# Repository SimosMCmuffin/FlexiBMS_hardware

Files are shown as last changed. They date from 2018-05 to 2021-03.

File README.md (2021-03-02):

# Note, this is not the hardware version of the "Lite"-version of the FlexiBMS, but an earlier tested and discontinued/abandoned concept of the BMS design. Lite HW is a new project that was started after this HW project was discontinued and is not currently in open-source circulation HW design wise.

# FlexiBMS_hardware
Open Source BMS developed by Simo Sihvonen (Simos MCmuffin) with the Esk8 community, for the Esk8 community.

This project was inspired by Raphael Chang's Battman project's hardware design (https://github.com/raphaelchang/battman-hardware)

More current news and happening related to this project can be found and followed over at the project thread at the electic-skateboard.builders forum: 
http://www.electric-skateboard.builders/t/flexibms-0-2-hw-under-work-flexible-configuration-and-charging-bms/46117

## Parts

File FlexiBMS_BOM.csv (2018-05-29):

Title | FlexiBMS
Revision | 0.2
Date | 2018-05-06
Generated | 29.5.2018 21:36:46
Company | SiMoS MCmuffin / Simo Sihvonen
Comment 1
Comment 2
Comment 3
Comment 4
Total Parts | 204
Total Unique Parts | 56
Ref | Value | Qty | Footprint | Datasheet | B25/85 | MFG | Power | TempCo. | Tol.
C1 C3 C5 C6 C7 C9 C11 C12 C27 C31 C37 C38 C39 C42 C44 C45 C46 C47 | 2µ2,16V | 18 | Capacitors_SMD:C_0603 |  |  | ANY |  | X5R
C2 C4 C63 C64 C65 | 10µ,63V | 5 | Capacitors_SMD:C_1210 |  |  | ANY |  | X7R
C8 C10 C13 C14 C15 C16 C17 C18 C19 C20 C21 C22 C23 C24 C25 C28 C30 C32 C33 C34 C43 | 100n,100V | 21 | Capacitors_SMD:C_0603 |  |  | ANY |  | X7R
C26 | 1µ,63V | 1 | Capacitors_SMD:C_1210 |  |  | ANY
C29 | 47µ,6V3 | 1 | Capacitors_SMD:C_1206 |  |  | ANY |  | X5R
C35 | 6n8,50V | 1 | Capacitors_SMD:C_0603 |  |  | ANY |  | X7R
C36 | 10µ,16V | 1 | Capacitors_SMD:C_1206 |  |  | ANY |  | X7R
C40 | 100µ,35V | 1 | Capacitors_SMD:CP_Elec_6.3x7.7 |  |  | EEE-FPV101XAP
C41 | 100µ,63V | 1 | Capacitors_SMD:CP_Elec_10x10 |  |  | EEE-FK1J101P
D1 | 12V | 1 | Diodes_SMD:D_SOD-323 |  |  | MM3Z12VT1G
D2 D3 D7 D9 D11 D13 D15 D17 D19 D21 D23 D25 D27 D29 D34 | LED | 15 | LEDs:LED_0603 |  |  | 150060RS75000
D4 D35 | CUS520 | 2 | Diodes_SMD:D_SOD-323 |  |  | CUS520 H3F
D5 | 62V | 1 | Diodes_SMD:D_SOD-123 |  |  | CMHZ5265B TR
D6 D8 D10 D12 D14 D16 D18 D20 D22 D24 D26 D28 | 7V5 | 12 | Diodes_SMD:D_SOD-323 |  |  | MM3Z7V5T1G
D30 | 53Vwm | 1 | Diodes_SMD:D_SMA |  |  | P4SMA62A-E3/61
D31 | 5,0Vwm | 1 | Diodes_SMD:D_SOD-123F |  |  | SMF5.0
D32 D33 | FSV1060V | 2 | TO_SOT_Packages_SMD:TO-277A |  |  | FSV1060V
J1 | Conn_02x08_Odd_Even | 1 | Pin_Headers:Pin_Header_Straight_2x08_Pitch2.54mm |  |  | PREC008DAAN-RC/"PPTC082LFBN-RC"/"SFH210-PPPC-D08-ID-BK"
J2 | USB_OTG | 1 | Connectors_USB:USB_Micro-B_Molex_47346-0001 |  |  | 10118192-0001LF OR "1051330011"
J3 | Conn_02x02 | 1 | Socket_Strips:Socket_Strip_Straight_2x02_Pitch2.54mm_SMD |  |  | M20-8750242
J4 J5 | JST_SMD_PH-04 | 2 | Connectors_JST:JST_PH_B4B-PH-SM4-TB_04x2.00mm_Straight |  |  | B4B-PH-SM4-TB(LF)(SN)
J6 | JST_XH-13 | 1 | Connectors_JST:JST_XH_S13B-XH-A_13x2.50mm_Angled |  |  | S13B-XH-A(LF)(SN)/"B13B-XH-A(LF)(SN)"
J7 J8 | GS3 | 2 | Connectors:GS3 |  |  | SolderBridge
L1 L2 L4 | BLM31PG330SN1L | 3 | Inductors_SMD:L_1206 |  |  | BLM31PG330SN1L
L3 | 22µ | 1 | Inductors_SMD:L_1210 |  |  | CBC3225T220MR
L5 | 22µ,6.3A | 1 | Custom_footprints:HC9 |  |  | HC9-220-R
LS1 | Speaker | 1 | Custom_footprints:CSS-0575 |  |  | CSS-0575A-SMT-TR
Q1 | DMP6023LE-13 | 1 | TO_SOT_Packages_SMD:SOT-223-3_TabPin2 |  |  | DMP6023LE-13
Q2 | DMN55D0UT-7 | 1 | smd-semi:SOT-523 |  |  | DMN55D0UT-7
Q3 Q4 | PMV50XPR | 2 | TO_SOT_Packages_SMD:SOT-23 |  |  | PMV50XPR
Q5 Q6 Q7 Q8 Q9 Q10 Q11 Q12 Q13 Q14 Q15 Q16 | BSS84PW | 12 | TO_SOT_Packages_SMD:SOT-323_SC-70 |  |  | BSS84PWH6327XTSA1
Q17 | BSZ100N06NSATMA1 | 1 | Custom_footprints:PG-TDSON-8 |  |  | BSZ100N06NSATMA1
R1 R72 R74 | 36k | 3 | Resistors_SMD:R_0603 |  |  | ANY |  |  | 1%
R2 R3 R71 | 510k | 3 | Resistors_SMD:R_0603 |  |  | ANY |  |  | 1%
R4 R6 R21 R23 R25 | 1M | 5 | Resistors_SMD:R_0603 |  |  | ANY |  |  | 1%
R5 R7 | 51k | 2 | Resistors_SMD:R_0603 |  |  | ANY |  |  | 1%
R8 R17 | 220k | 2 | Resistors_SMD:R_0603 |  |  | ANY |  |  | 1%
R9 R10 R15 R16 R18 R67 | 10k | 6 | Resistors_SMD:R_0603 |  |  | ANY |  |  | 1%
R11 R12 R19 R24 R68 | 4k7 | 5 | Resistors_SMD:R_0603 |  |  | ANY |  |  | 1%
R13 R14 R20 R22 R26 R73 R76 R77 | 120R | 8 | Resistors_SMD:R_0603 |  |  | ANY |  |  | 1%
R27 R28 R30 R31 R33 R34 R36 R37 R39 R40 R42 R43 R45 R46 R48 R49 R51 R52 R54 R55 R57 R58 R60 R61 R63 | 120R | 25 | Resistors_SMD:R_0402 |  |  | ANY |  |  | 1%
R29 R32 R35 R38 R41 R44 R47 R50 R53 R56 R59 R62 | 51R | 12 | Resistors_SMD:R_0805 |  |  | ANY | 0.5W |  | 5%
R64 R65 | 10R | 2 | Resistors_SMD:R_0603 |  |  | ANY |  |  | 1%
R66 | 10m | 1 | Resistors_SMD:R_1206 |  |  | ANY | 0.75W |  | 1%
R69 | 15m | 1 | Resistors_SMD:R_1206 |  |  | ANY | 0.75W |  | 1%
R70 | 18k | 1 | Resistors_SMD:R_0603 |  |  | ANY |  |  | 1%
SW1 SW2 | SW_Push | 2 | Buttons_Switches_SMD:SW_SPST_PTS810 |  |  | PTS810 SJK 250 SMTR LFS
TH2 | 10k | 1 | Resistors_SMD:R_0603 |  | 4300K | NCP18XH103J03RB |  |  | 5%
U1 U9 | AP2210N-3.3 | 2 | TO_SOT_Packages_SMD:SOT-23 |  |  | AP2210N-3.3TRG1
U2 | STM32L433CCT6 | 1 | Housings_QFP:LQFP-48_7x7mm_Pitch0.5mm |  |  | STM32L433CCT6
U3 | LTC6803-3 | 1 | Custom_footprints:FSOP-44_5.3x13.0mm_Pitch0.5mm |  |  | LTC6803IG-3#PBF
U4 | MAX17502F | 1 | Housings_DFN_QFN:DFN-10-1EP_2x3mm_Pitch0.5mm |  |  | MAX17502FATB+T
U5 | ISL28022 | 1 | Housings_SSOP:MSOP-10_3x3mm_Pitch0.5mm |  |  | ISL28022FUZ-T7A
U6 | LTC3873 | 1 | TO_SOT_Packages_SMD:TSOT-23-8 |  |  | LTC3873ETS8#TRMPBF
U7 | MAX5215 | 1 | Housings_SSOP:MSOP-8_3x3mm_Pitch0.65mm |  |  | MAX5215GUA+
U8 | TCAN330 | 1 | TO_SOT_Packages_SMD:SOT-23-8 |  |  | TCAN330DCNR
BOM made with KICAD_BOM_WIZARD (https://github.com/HashDefineElectronics/KiCad_BOM_Wizard.git)
Generated 29.5.2018 21:36:46

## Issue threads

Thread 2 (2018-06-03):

Some questions

Linjieqiang, 2018-06-03:
Hello Simos.

Happy to see your BMS project.

1. Why not use the TI BQ76940 not use LTC6803 as the Analog front chip to catch the each cell voltage and current and temperature?
2. Why not use the TI BQ76200 to controll the power switch?

SimosMCmuffin, 2018-06-04:
Good questions.

1. **Why not use TI's BQ769XX series ICs for the cell stack monitoring?** I had in fact in the beginning of the development looked at the before mentioned TI's chips, as a lower priced alternative to the LTC6803 series, but discovered the disappointing fact, that the overall cell support was less flexible with the TI's chips. I have pasted below a screenshot from the BQ769XX datasheet which shows the problem, there is no IC model that would support 4-12 amount of series cells and that is why I went with the LTC6803, because it gave the most flexibility for the series cells configuration.

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

2. **Why not use TI's BQ76200 for controlling the charge FET?** Remember that there is no discharge control on the main module, it would only be controlling a single high-side N-channel FET ideally, but that doesn't really make that much sense in the end. The charging currents we're talking about are low enough that a decently sized P-channel FET can be used with a simple low side N-channel FET to activate it. So IMO it's cheaper, less complex and uses less board space to go with the P-channel implementation.

Linjieqiang, 2018-06-04:
I am designing my BMS for my e-bike with TI BQ76940 12S.

Closed 2018-06-04.

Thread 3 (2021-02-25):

LiPo HV

13022591351, 2021-02-25:
Does the hardware support 4.35V high voltage LiPo?

SimosMCmuffin, 2021-03-01:
I will first ask a clarification question.

Are aware that this hardware repo is not the Lite-version of the FlexiBMS project, that is currently developed and sold, but an older, currently abandoned HW version of it?

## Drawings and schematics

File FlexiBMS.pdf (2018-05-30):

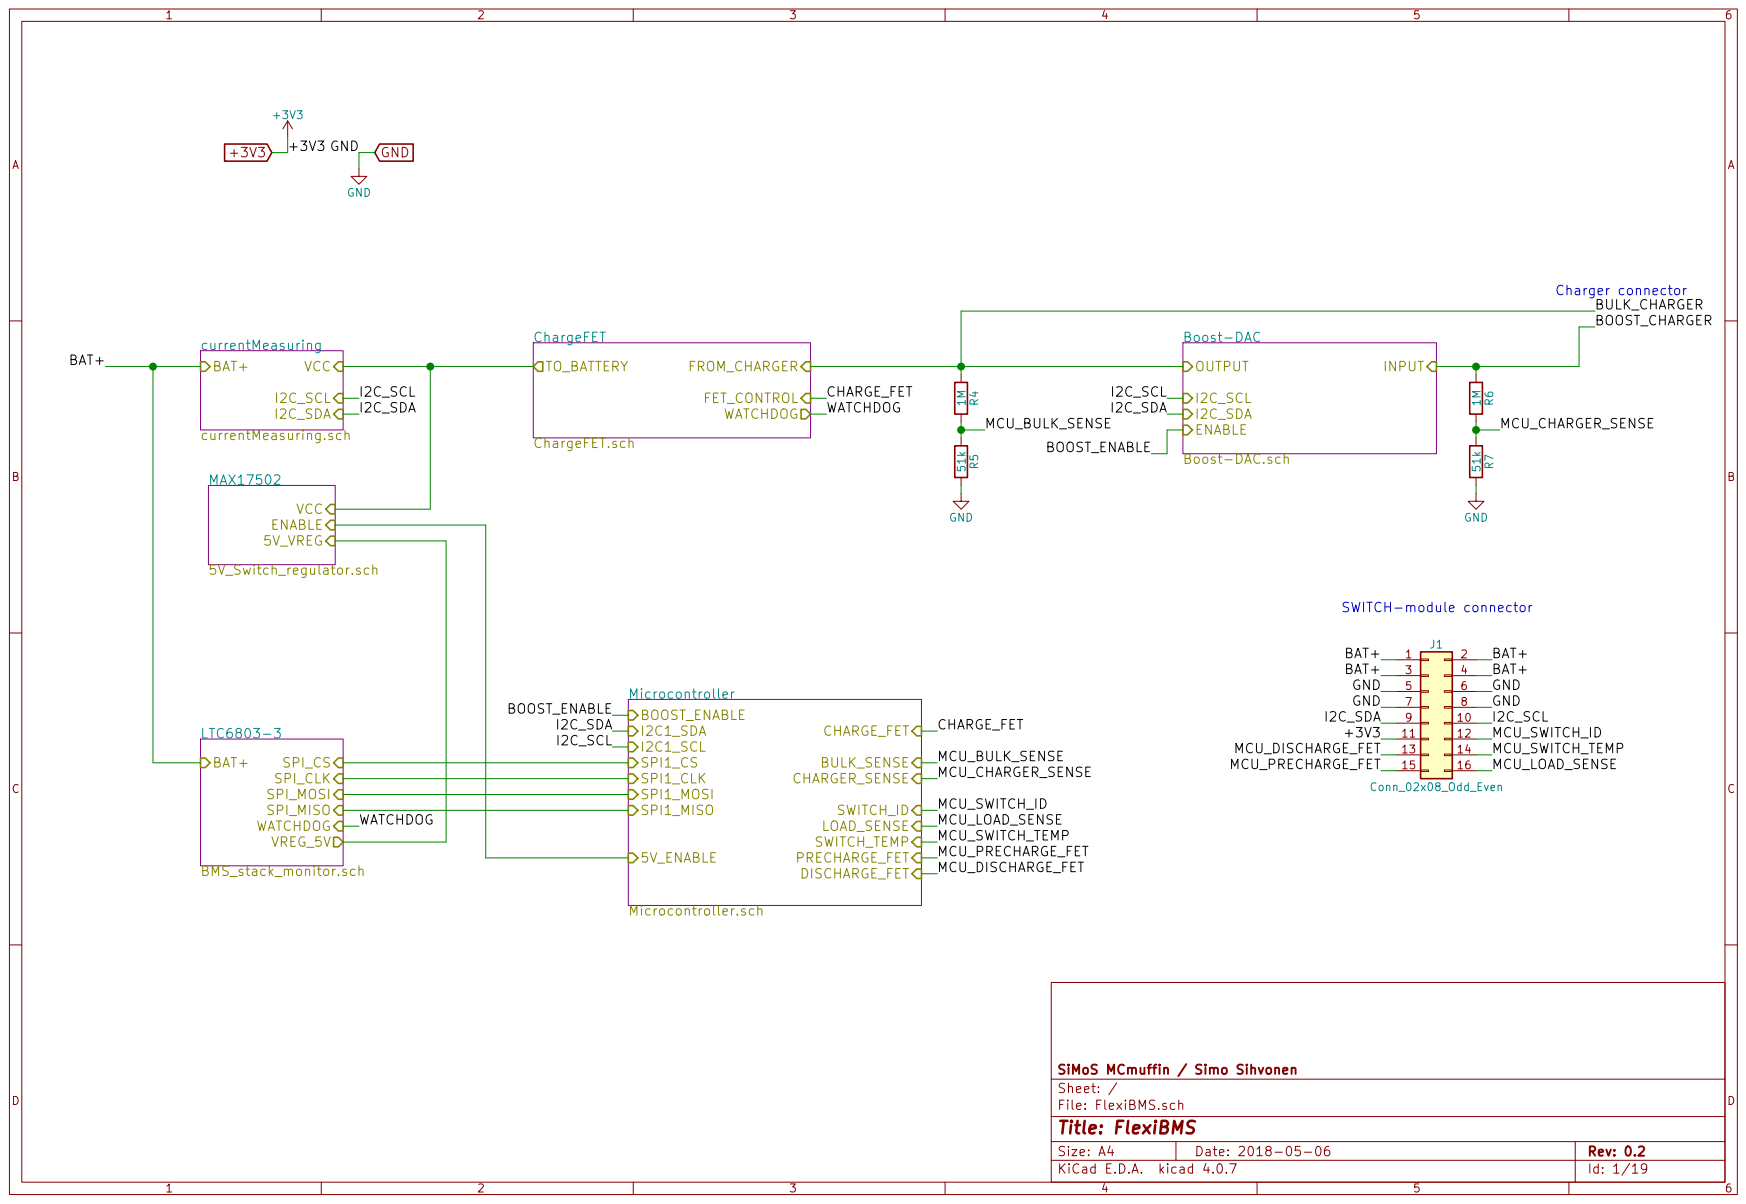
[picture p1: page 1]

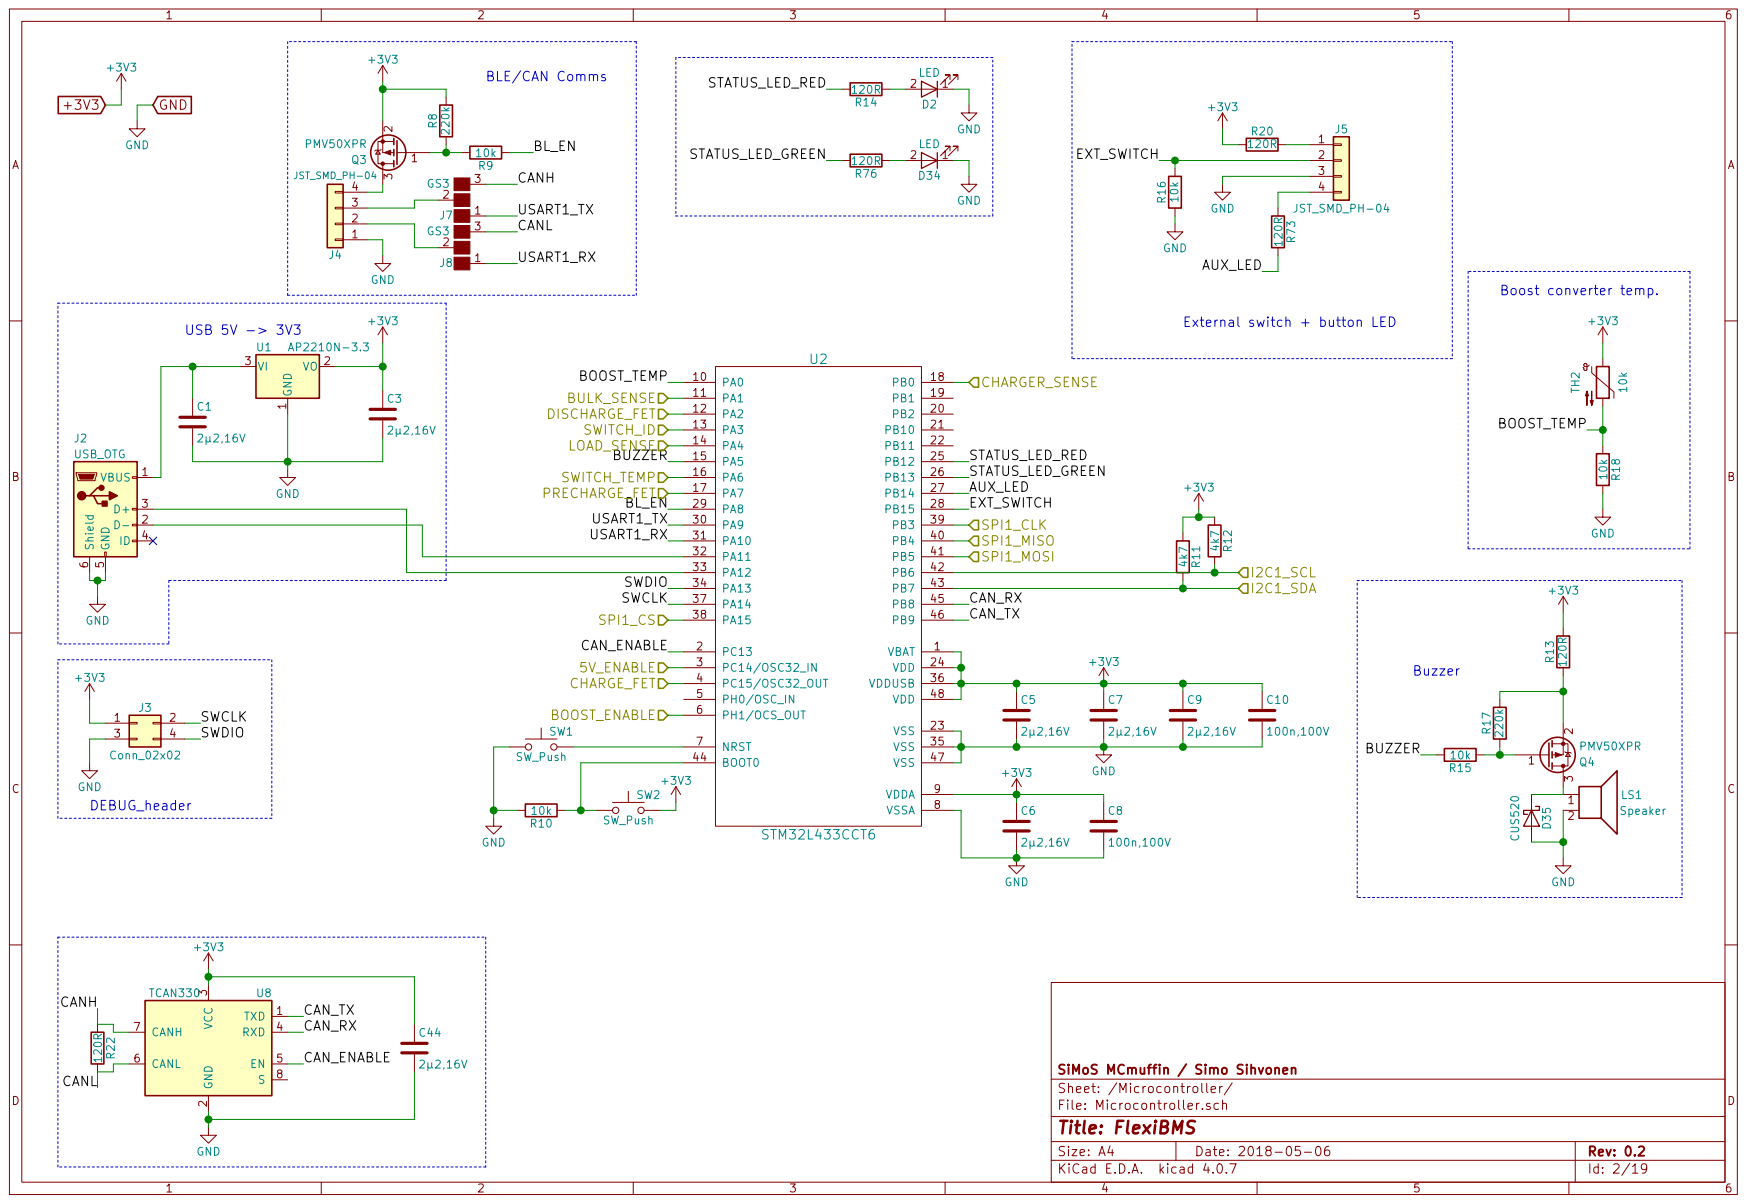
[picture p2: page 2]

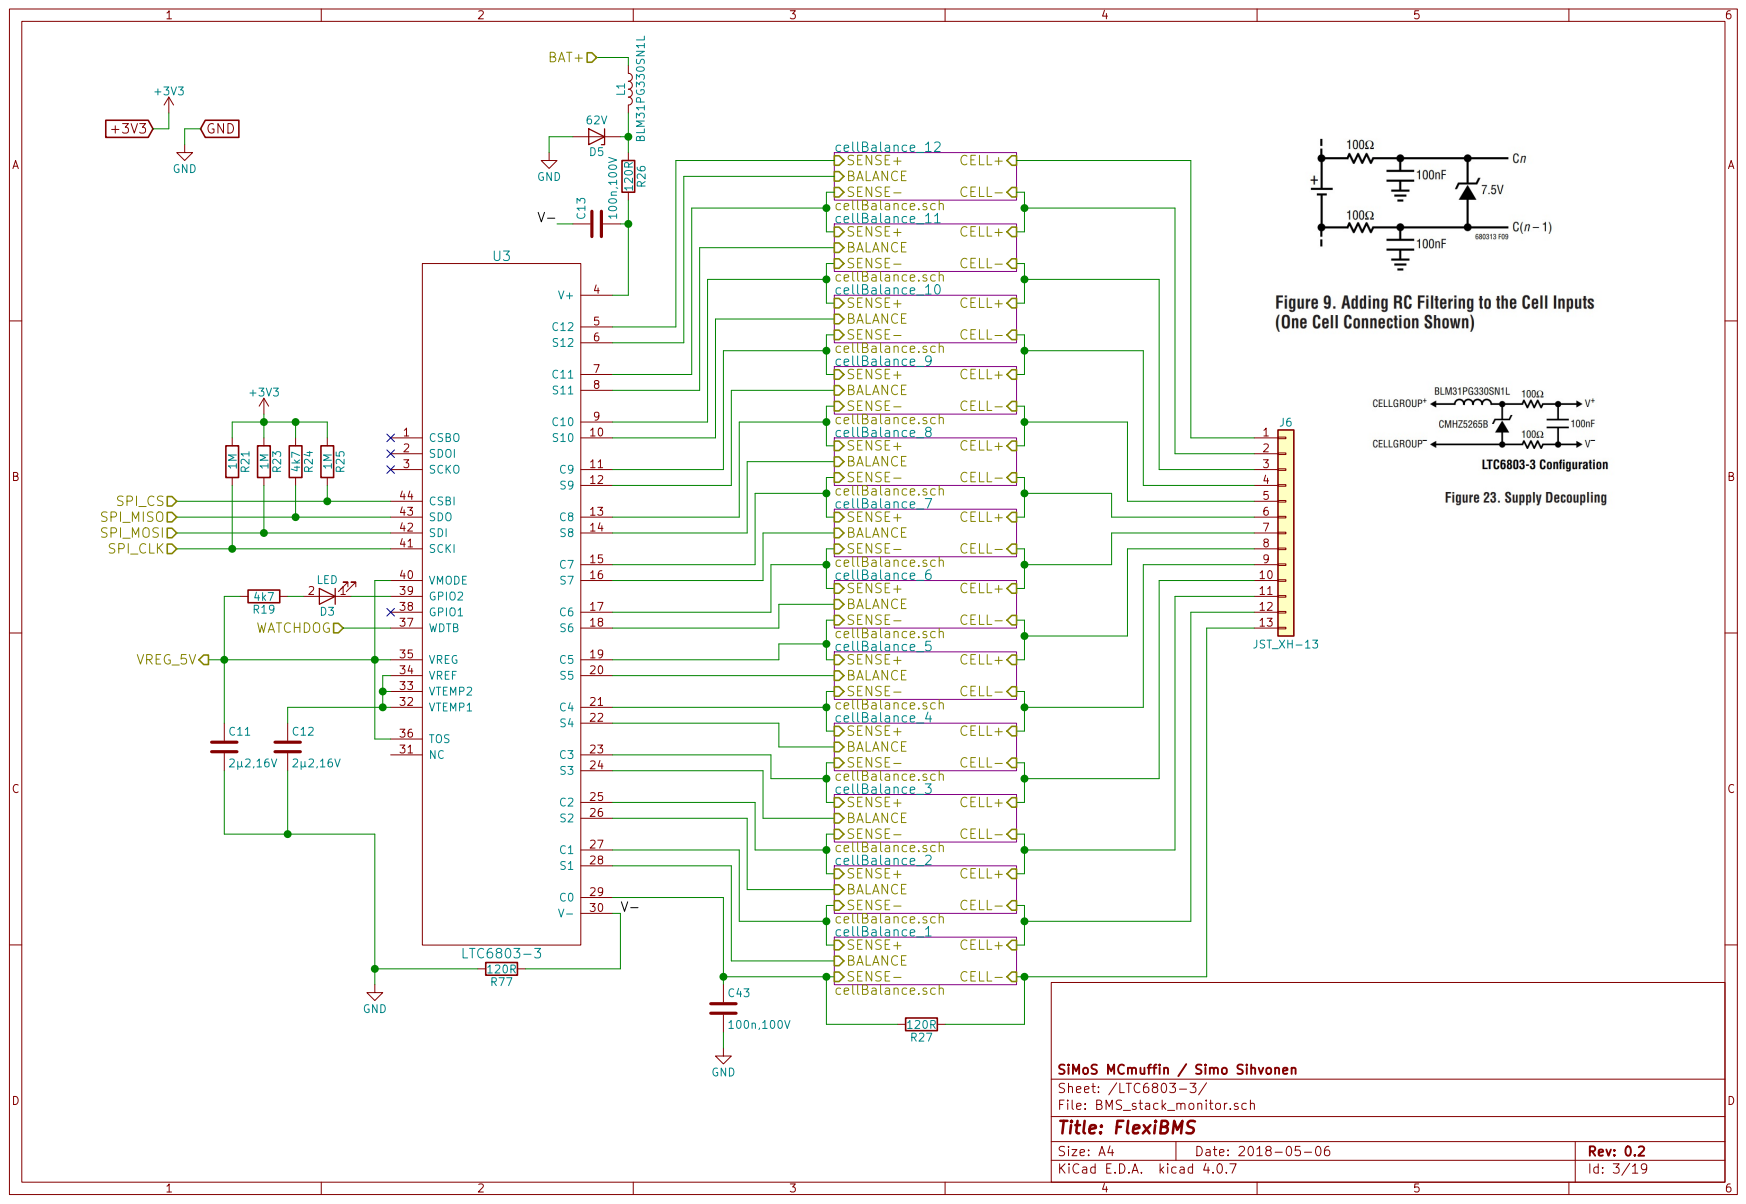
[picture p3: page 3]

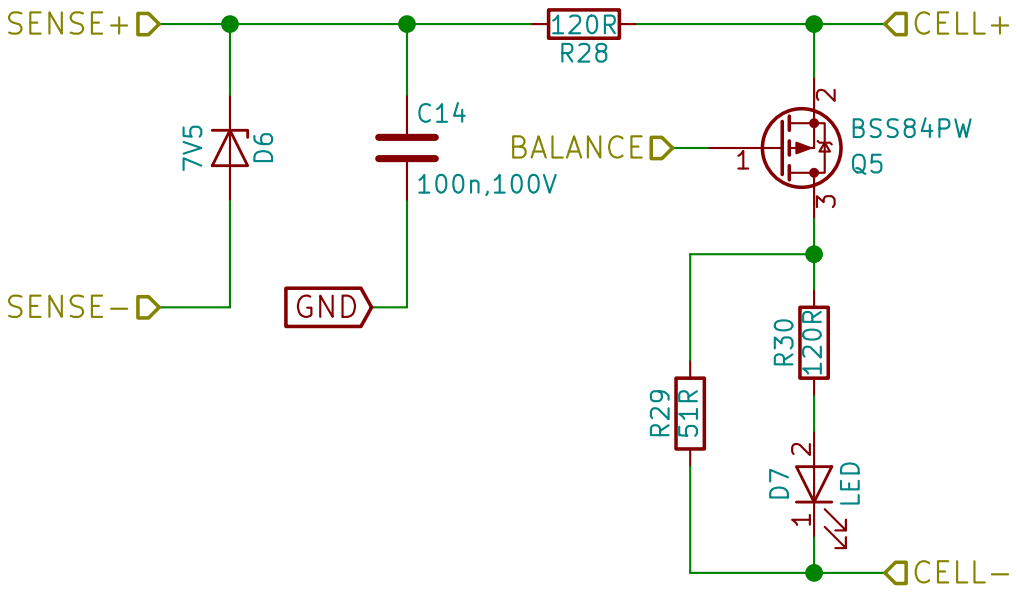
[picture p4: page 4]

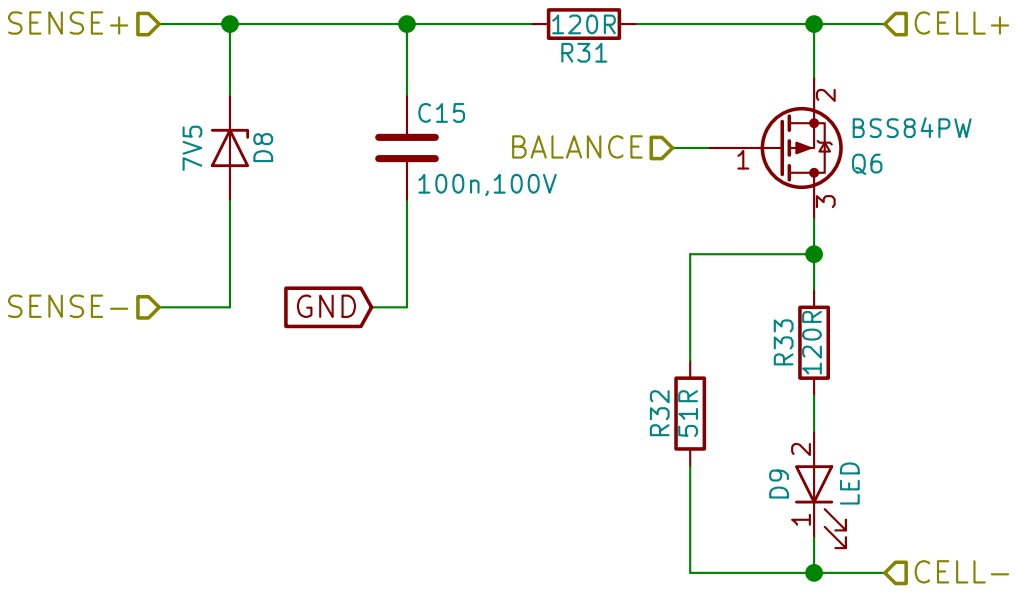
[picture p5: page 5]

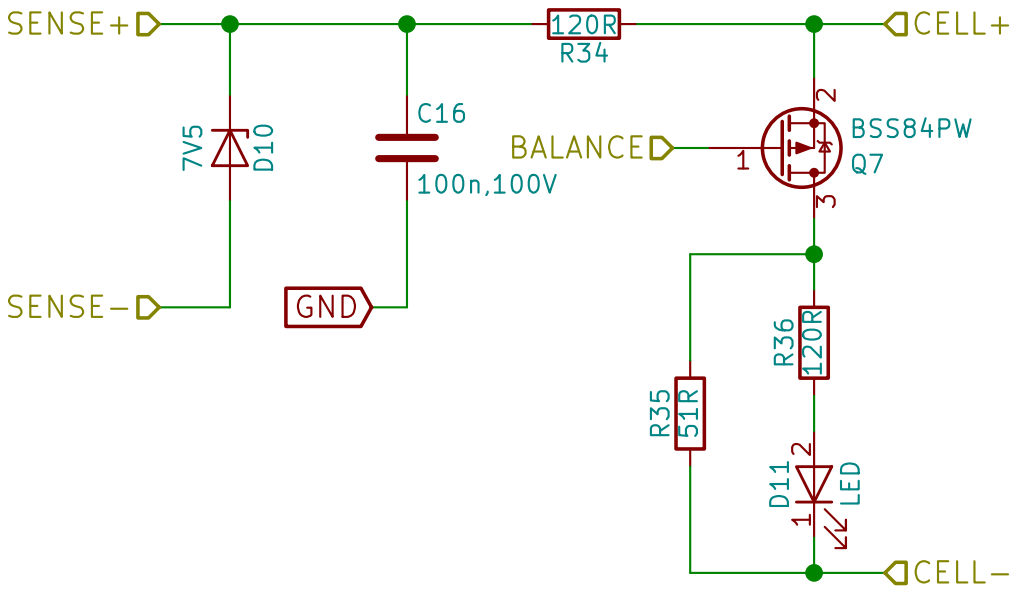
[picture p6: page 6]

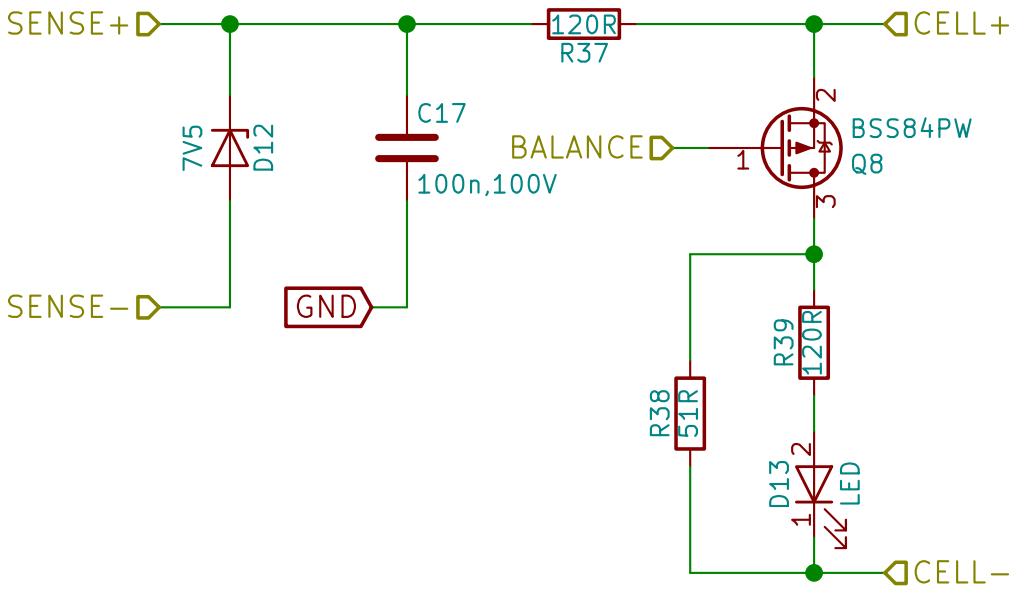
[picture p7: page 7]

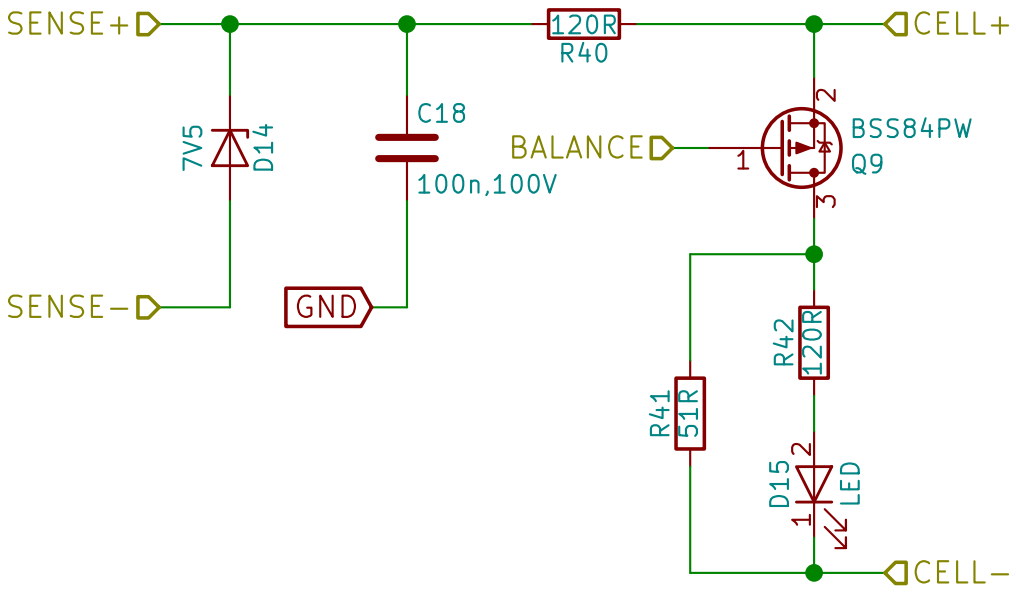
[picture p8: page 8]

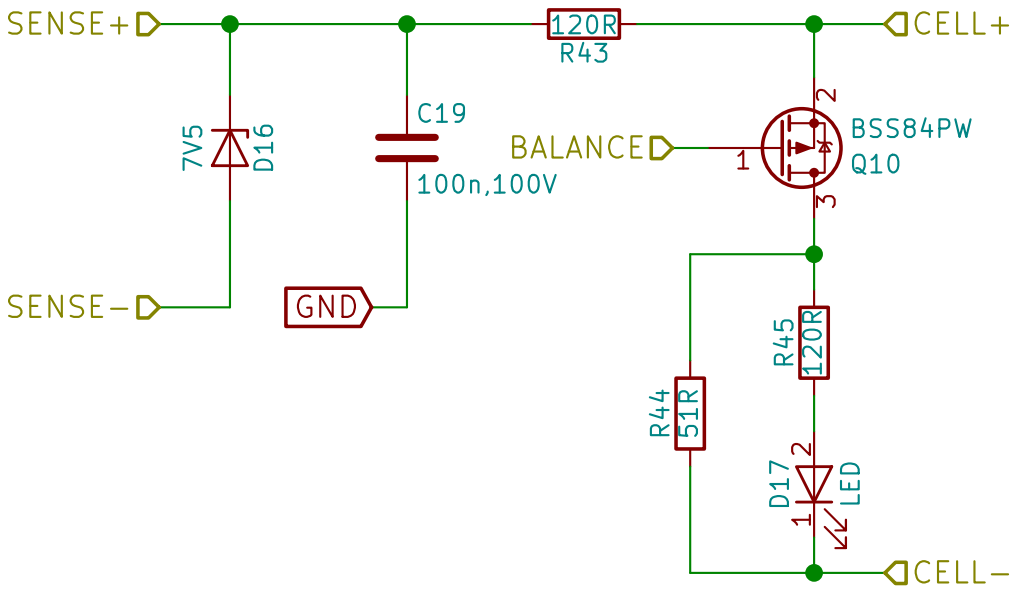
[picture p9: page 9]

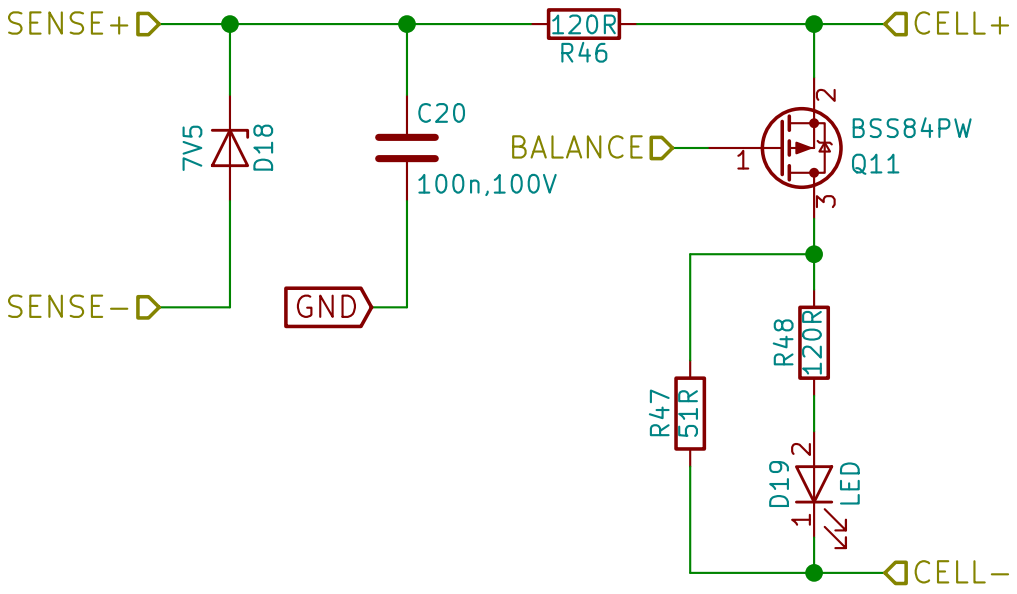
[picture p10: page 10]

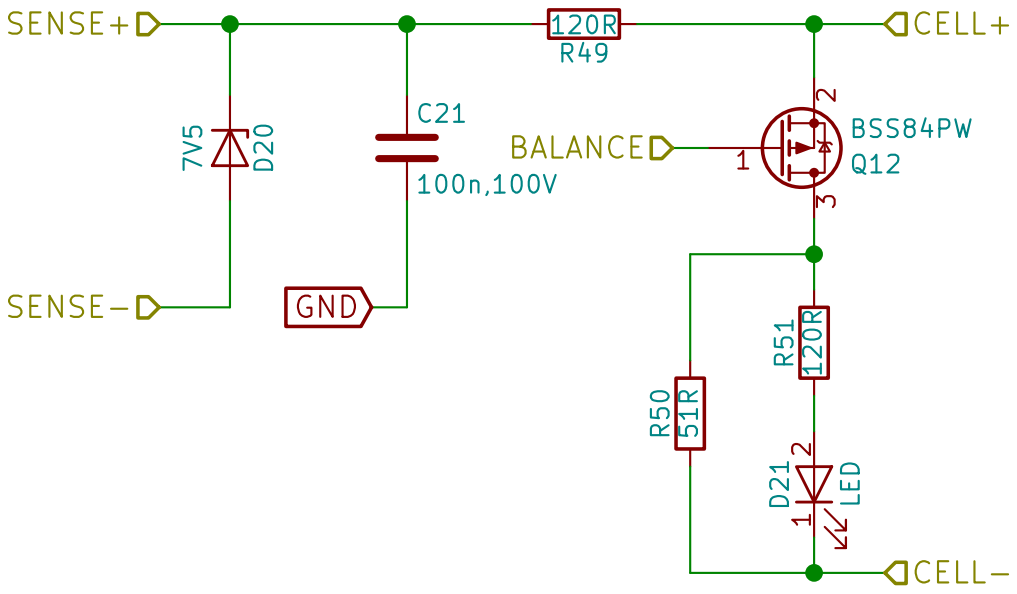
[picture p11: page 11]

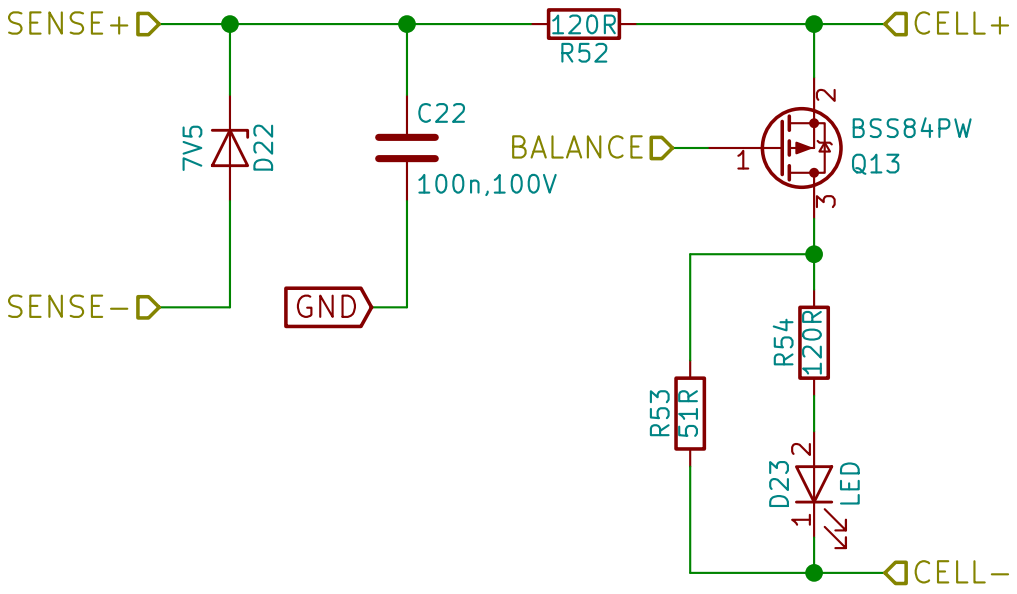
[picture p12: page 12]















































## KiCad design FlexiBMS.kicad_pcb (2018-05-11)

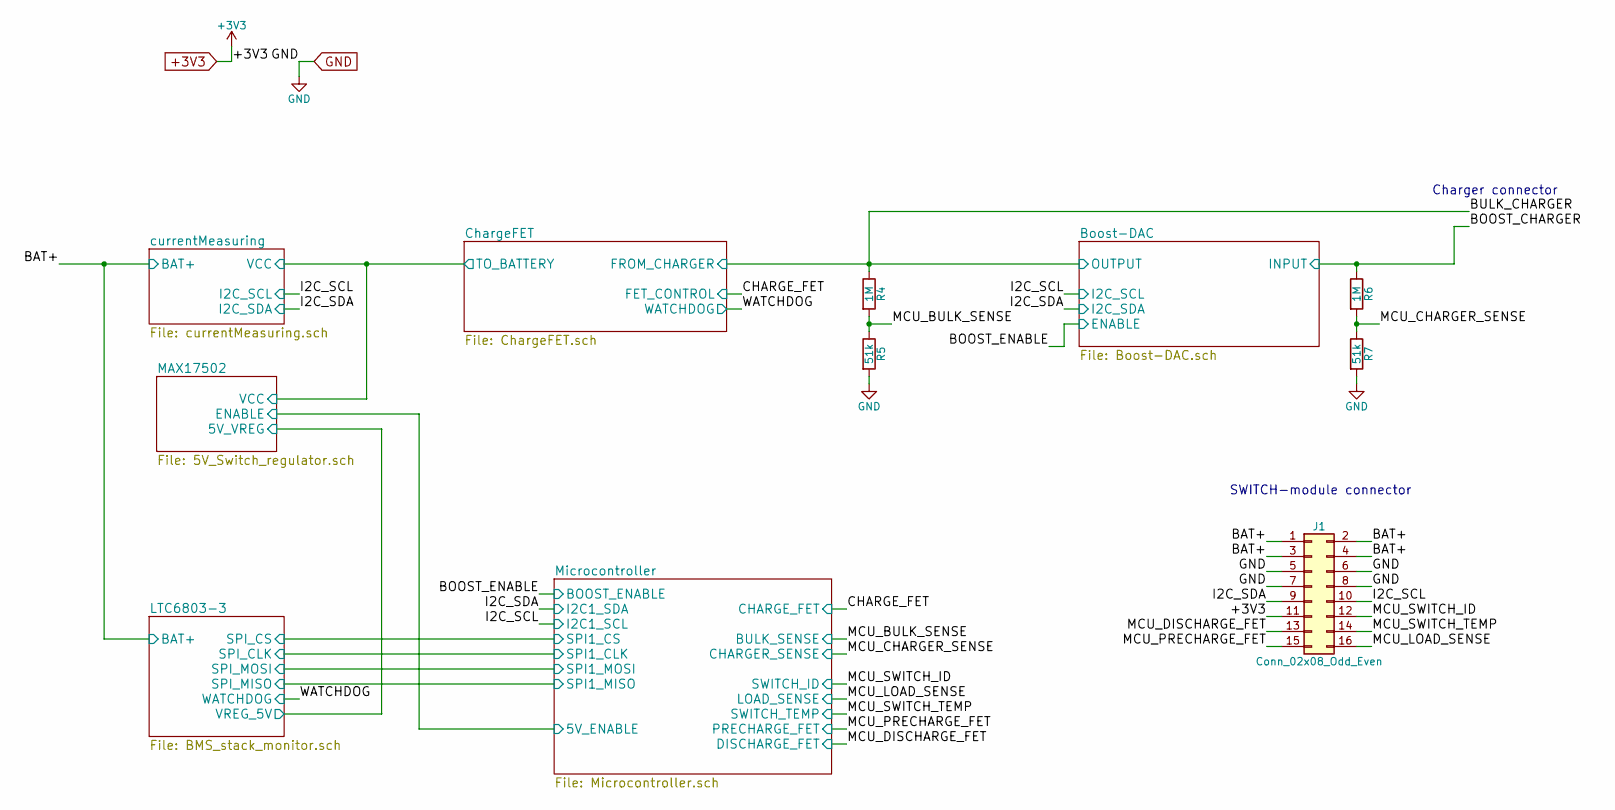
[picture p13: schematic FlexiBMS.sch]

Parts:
J1: Conn_02x08_Odd_Even; Pin_Header_Straight_2x08_Pitch2.54mm
R4, R6: 1M; R_0603
R5, R7: 51k; R_0603

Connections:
+3V3: J1.11; also elsewhere on the board
/BAT+: J1.1, J1.2, J1.3, J1.4; also elsewhere on the board
/BOOST_CHARGER: R6.1; also elsewhere on the board
/BULK_CHARGER: R4.1; also elsewhere on the board
/I2C_SCL: J1.10; also elsewhere on the board
/I2C_SDA: J1.9; also elsewhere on the board
/MCU_BULK_SENSE: R4.2, R5.1; also elsewhere on the board
/MCU_CHARGER_SENSE: R6.2, R7.1; also elsewhere on the board
/MCU_DISCHARGE_FET: J1.13; also elsewhere on the board
/MCU_LOAD_SENSE: J1.16; also elsewhere on the board
/MCU_PRECHARGE_FET: J1.15; also elsewhere on the board
/MCU_SWITCH_ID: J1.12; also elsewhere on the board
/MCU_SWITCH_TEMP: J1.14; also elsewhere on the board
GND: J1.5, J1.6, J1.7, J1.8, R5.2, R7.2; also elsewhere on the board

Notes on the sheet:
SWITCH-module connector
Charger connector

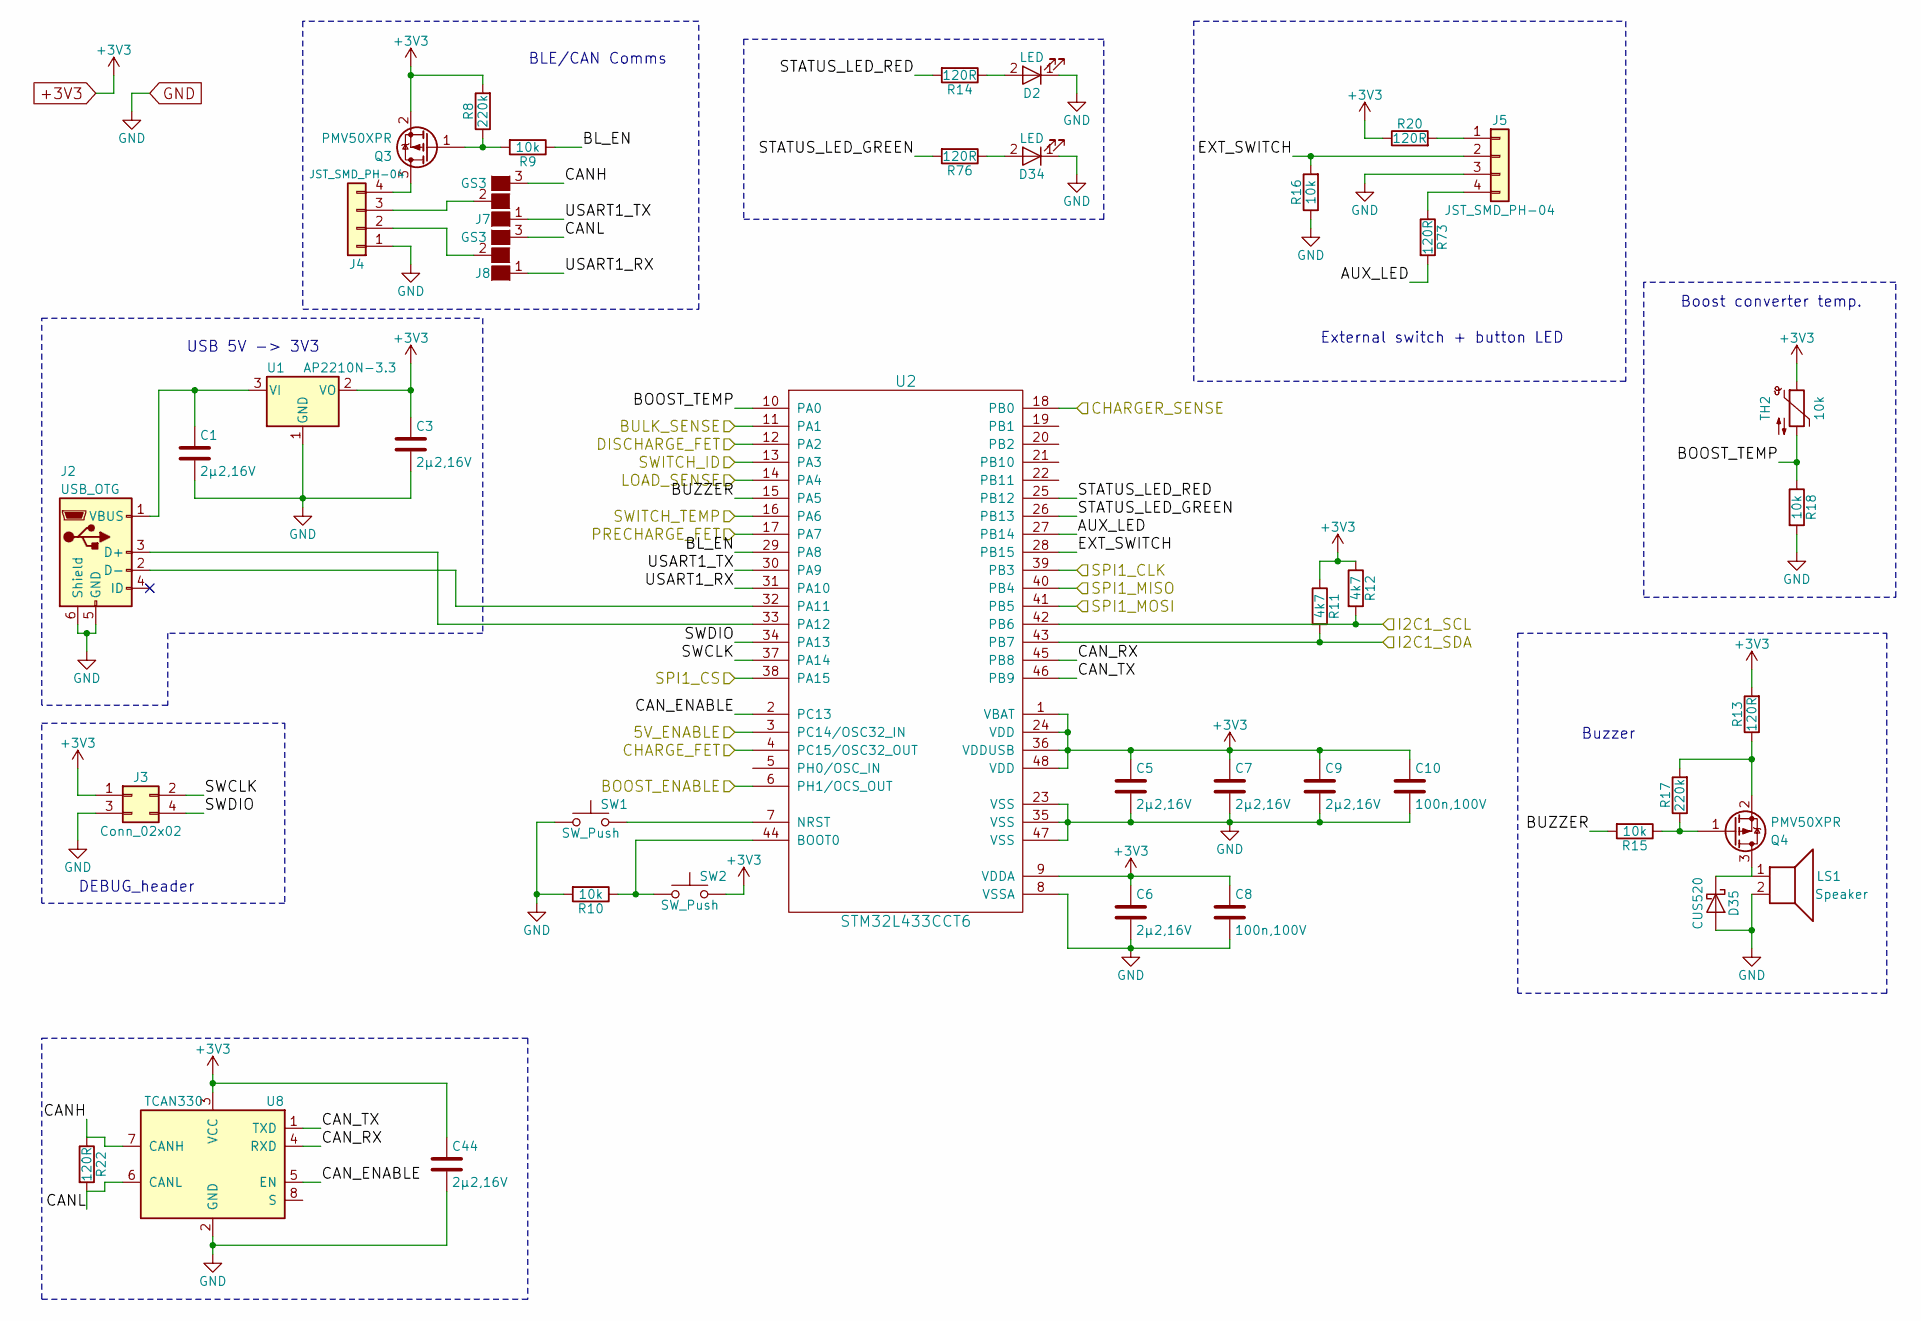
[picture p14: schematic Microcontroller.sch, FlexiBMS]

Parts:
C1, C3, C5, C6, C7, C9, C44: 2µ2,16V; C_0603
C8, C10: 100n,100V; C_0603
D2, D34: LED; LED_0603
D35: CUS520; D_SOD-323
J2: USB_OTG; USB_Micro-B_Molex_47346-0001
J3: Conn_02x02; Socket_Strip_Straight_2x02_Pitch2.54mm_SMD
J4, J5: JST_SMD_PH-04; JST_PH_B4B-PH-SM4-TB_04x2.00mm_Straight
J7, J8: GS3
LS1: Speaker; CSS-0575
Q3, Q4: PMV50XPR; SOT-23
R8, R17: 220k; R_0603
R9, R10, R15, R16, R18: 10k; R_0603
R11, R12: 4k7; R_0603
R13, R14, R20, R22, R73, R76: 120R; R_0603
SW1, SW2: SW_Push; SW_SPST_PTS810
TH2: 10k; R_0603
U1: AP2210N-3.3; SOT-23
U2: STM32L433CCT6; LQFP-48_7x7mm_Pitch0.5mm
U8: TCAN330; SOT-23-8

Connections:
+3V3: C3.1, C5.1, C6.1, C7.1, C8.1, C9.1, C10.1, C44.1, J3.1, Q3.2 (S), R8.2, R11.1, R12.1, R13.2, R20.1, SW2.2, TH2.1, U1.2 (VO), U2.1 (VBAT), U2.9 (VDDA), U2.24 (VDD), U2.36 (VDDUSB), U2.48 (VDD), U8.3 (VCC); also elsewhere on the board
/BOOST_ENABLE: U2.6 (PH1/OCS_OUT); also elsewhere on the board
/CHARGE_FET: U2.4 (PC15/OSC32_OUT); also elsewhere on the board
/I2C_SCL: R12.2, U2.42 (PB6); also elsewhere on the board
/I2C_SDA: R11.2, U2.43 (PB7); also elsewhere on the board
/MCU_BULK_SENSE: U2.11 (PA1); also elsewhere on the board
/MCU_CHARGER_SENSE: U2.18 (PB0); also elsewhere on the board
/MCU_DISCHARGE_FET: U2.12 (PA2); also elsewhere on the board
/MCU_LOAD_SENSE: U2.14 (PA4); also elsewhere on the board
/MCU_PRECHARGE_FET: U2.17 (PA7); also elsewhere on the board
/MCU_SWITCH_ID: U2.13 (PA3); also elsewhere on the board
/MCU_SWITCH_TEMP: U2.16 (PA6); also elsewhere on the board
/Microcontroller/5V_ENABLE: U2.3 (PC14/OSC32_IN); also elsewhere on the board
/Microcontroller/AUX_LED: R73.2, U2.27 (PB14)
/Microcontroller/BL_EN: R9.1, U2.29 (PA8)
/Microcontroller/BOOST_TEMP: R18.1, TH2.2, U2.10 (PA0)
/Microcontroller/BUZZER: R15.2, U2.15 (PA5)
/Microcontroller/CANH: J7.3 (G3), R22.1, U8.7 (CANH)
/Microcontroller/CANL: J8.3 (G3), R22.2, U8.6 (CANL)
/Microcontroller/CAN_ENABLE: U2.2 (PC13), U8.5 (EN)
/Microcontroller/CAN_RX: U2.45 (PB8), U8.4 (RXD)
/Microcontroller/CAN_TX: U2.46 (PB9), U8.1 (TXD)
/Microcontroller/EXT_SWITCH: J5.2, R16.2, U2.28 (PB15)
/Microcontroller/SPI1_CLK: U2.39 (PB3); also elsewhere on the board
/Microcontroller/SPI1_CS: U2.38 (PA15); also elsewhere on the board
/Microcontroller/SPI1_MISO: U2.40 (PB4); also elsewhere on the board
/Microcontroller/SPI1_MOSI: U2.41 (PB5); also elsewhere on the board
/Microcontroller/STATUS_LED_GREEN: R76.2, U2.26 (PB13)
/Microcontroller/STATUS_LED_RED: R14.2, U2.25 (PB12)
/Microcontroller/SWCLK: J3.2, U2.37 (PA14)
/Microcontroller/SWDIO: J3.4, U2.34 (PA13)
/Microcontroller/USART1_RX: J8.1 (G1), U2.31 (PA10)
/Microcontroller/USART1_TX: J7.1 (G1), U2.30 (PA9)
GND: C1.2, C3.2, C5.2, C6.2, C7.2, C8.2, C9.2, C10.2, C44.2, D2.1 (K), D34.1 (K), D35.2 (A), J2.5 (GND), J2.6 (Shield), J3.3, J4.1, J5.3, LS1.2, R10.2, R16.1, R18.2, SW1.1, U1.1 (GND), U2.8 (VSSA), U2.23 (VSS), U2.35 (VSS), U2.47 (VSS), U8.2 (GND); also elsewhere on the board
unnamed: C1.1, J2.1 (VBUS), U1.3 (VI)
unnamed: D2.2 (A), R14.1
unnamed: D34.2 (A), R76.1
unnamed: D35.1 (K), LS1.1, Q4.3 (D)
unnamed: J2.2 (D-), U2.32 (PA11)
unnamed: J2.3 (D+), U2.33 (PA12)
unnamed: J4.2, J8.2 (G2)
unnamed: J4.3, J7.2 (G2)
unnamed: J4.4, Q3.3 (D)
unnamed: J5.1, R20.2
unnamed: J5.4, R73.1
unnamed: Q3.1 (G), R8.1, R9.2
unnamed: Q4.1 (G), R15.1, R17.1
unnamed: Q4.2 (S), R13.1, R17.2
unnamed: R10.1, SW2.1, U2.44 (BOOT0)
unnamed: SW1.2, U2.7 (NRST)

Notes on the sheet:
Boost converter temp.
External switch + button LED
BLE/CAN Comms
Buzzer
USB 5V -> 3V3
DEBUG_header

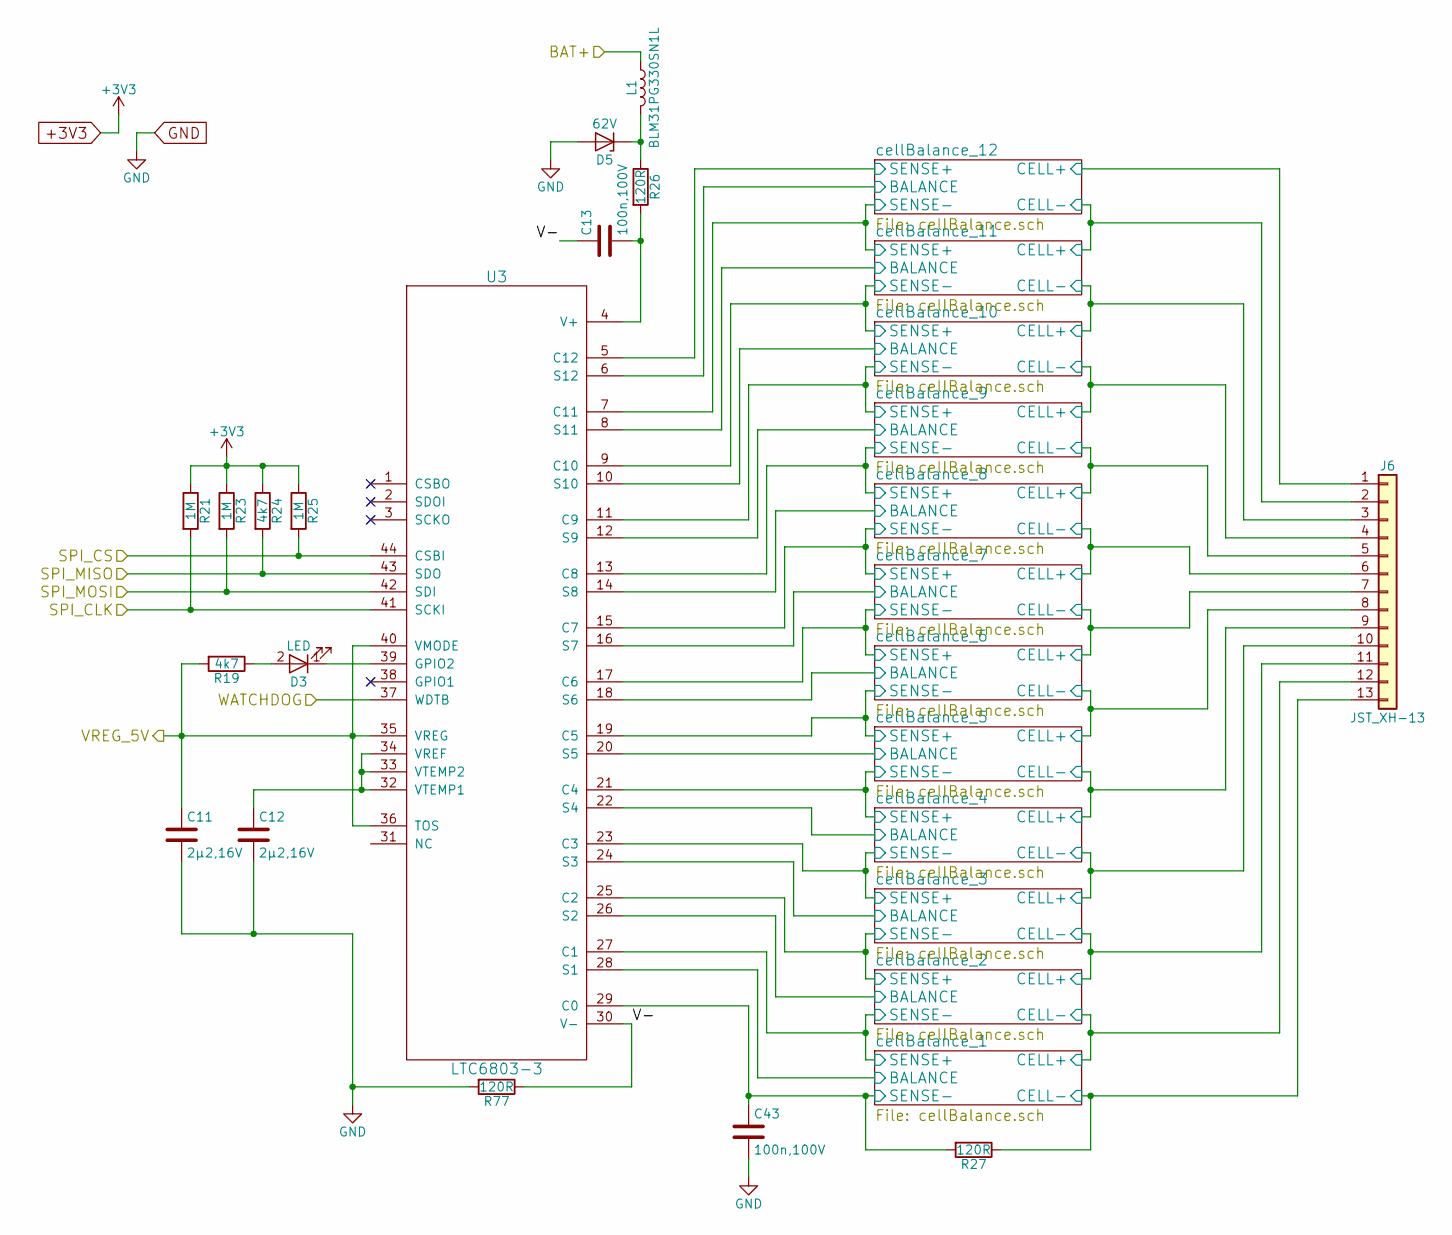
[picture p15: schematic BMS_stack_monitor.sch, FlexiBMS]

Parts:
C11, C12: 2µ2,16V; C_0603
C13, C43: 100n,100V; C_0603
D3: LED; LED_0603
D5: 62V; D_SOD-123
J6: JST_XH-13; JST_XH_S13B-XH-A_13x2.50mm_Angled
L1: BLM31PG330SN1L; L_1206
R19, R24: 4k7; R_0603
R21, R23, R25: 1M; R_0603
R26, R77: 120R; R_0603
R27: 120R; R_0402
U3: LTC6803-3; FSOP-44_5.3x13.0mm_Pitch0.5mm

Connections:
+3V3: R21.1, R23.1, R24.1, R25.1; also elsewhere on the board
/BAT+: L1.1; also elsewhere on the board
/LTC6803-3/V-: C13.1, R77.1, U3.30 (V-)
/LTC6803-3/cellBalance_1/BALANCE: U3.28 (S1); also elsewhere on the board
/LTC6803-3/cellBalance_1/CELL+: J6.12; also elsewhere on the board
/LTC6803-3/cellBalance_1/CELL-: J6.13, R27.1; also elsewhere on the board
/LTC6803-3/cellBalance_1/SENSE+: U3.27 (C1); also elsewhere on the board
/LTC6803-3/cellBalance_1/SENSE-: C43.1, R27.2, U3.29 (C0); also elsewhere on the board
/LTC6803-3/cellBalance_2/BALANCE: U3.26 (S2); also elsewhere on the board
/LTC6803-3/cellBalance_2/CELL+: J6.11; also elsewhere on the board
/LTC6803-3/cellBalance_2/SENSE+: U3.25 (C2); also elsewhere on the board
/LTC6803-3/cellBalance_3/BALANCE: U3.24 (S3); also elsewhere on the board
/LTC6803-3/cellBalance_3/CELL+: J6.10; also elsewhere on the board
/LTC6803-3/cellBalance_3/SENSE+: U3.23 (C3); also elsewhere on the board
/LTC6803-3/cellBalance_4/BALANCE: U3.22 (S4); also elsewhere on the board
/LTC6803-3/cellBalance_4/CELL+: J6.9; also elsewhere on the board
/LTC6803-3/cellBalance_4/SENSE+: U3.21 (C4); also elsewhere on the board
/LTC6803-3/cellBalance_5/BALANCE: U3.20 (S5); also elsewhere on the board
/LTC6803-3/cellBalance_5/CELL+: J6.8; also elsewhere on the board
/LTC6803-3/cellBalance_5/SENSE+: U3.19 (C5); also elsewhere on the board
/LTC6803-3/cellBalance_6/BALANCE: U3.18 (S6); also elsewhere on the board
/LTC6803-3/cellBalance_6/CELL+: J6.7; also elsewhere on the board
/LTC6803-3/cellBalance_6/SENSE+: U3.17 (C6); also elsewhere on the board
/LTC6803-3/cellBalance_7/BALANCE: U3.16 (S7); also elsewhere on the board
/LTC6803-3/cellBalance_7/CELL+: J6.6; also elsewhere on the board
/LTC6803-3/cellBalance_7/SENSE+: U3.15 (C7); also elsewhere on the board
/LTC6803-3/cellBalance_8/BALANCE: U3.14 (S8); also elsewhere on the board
/LTC6803-3/cellBalance_8/CELL+: J6.5; also elsewhere on the board
/LTC6803-3/cellBalance_8/SENSE+: U3.13 (C8); also elsewhere on the board
/LTC6803-3/cellBalance_9/BALANCE: U3.12 (S9); also elsewhere on the board
/LTC6803-3/cellBalance_9/CELL+: J6.4; also elsewhere on the board
/LTC6803-3/cellBalance_9/SENSE+: U3.11 (C9); also elsewhere on the board
/LTC6803-3/cellBalance_10/BALANCE: U3.10 (S10); also elsewhere on the board
/LTC6803-3/cellBalance_10/CELL+: J6.3; also elsewhere on the board
/LTC6803-3/cellBalance_10/SENSE+: U3.9 (C10); also elsewhere on the board
/LTC6803-3/cellBalance_11/BALANCE: U3.8 (S11); also elsewhere on the board
/LTC6803-3/cellBalance_11/CELL+: J6.2; also elsewhere on the board
/LTC6803-3/cellBalance_11/SENSE+: U3.7 (C11); also elsewhere on the board
/LTC6803-3/cellBalance_12/BALANCE: U3.6 (S12); also elsewhere on the board
/LTC6803-3/cellBalance_12/CELL+: J6.1; also elsewhere on the board
/LTC6803-3/cellBalance_12/SENSE+: U3.5 (C12); also elsewhere on the board
/MAX17502/5V_VREG: C11.1, R19.2, U3.35 (VREG), U3.36 (TOS), U3.40 (VMODE); also elsewhere on the board
/Microcontroller/SPI1_CLK: R21.2, U3.41 (SCKI); also elsewhere on the board
/Microcontroller/SPI1_CS: R25.2, U3.44 (CSBI); also elsewhere on the board
/Microcontroller/SPI1_MISO: R24.2, U3.43 (SDO); also elsewhere on the board
/Microcontroller/SPI1_MOSI: R23.2, U3.42 (SDI); also elsewhere on the board
/WATCHDOG: U3.37 (WDTB); also elsewhere on the board
GND: C11.2, C12.2, C43.2, D5.2 (A), R77.2; also elsewhere on the board
unnamed: C12.1, U3.32 (VTEMP1), U3.33 (VTEMP2), U3.34 (VREF)
unnamed: C13.2, R26.2, U3.4 (V+)
unnamed: D3.1 (K), U3.39 (GPIO2)
unnamed: D3.2 (A), R19.1
unnamed: D5.1 (K), L1.2, R26.1

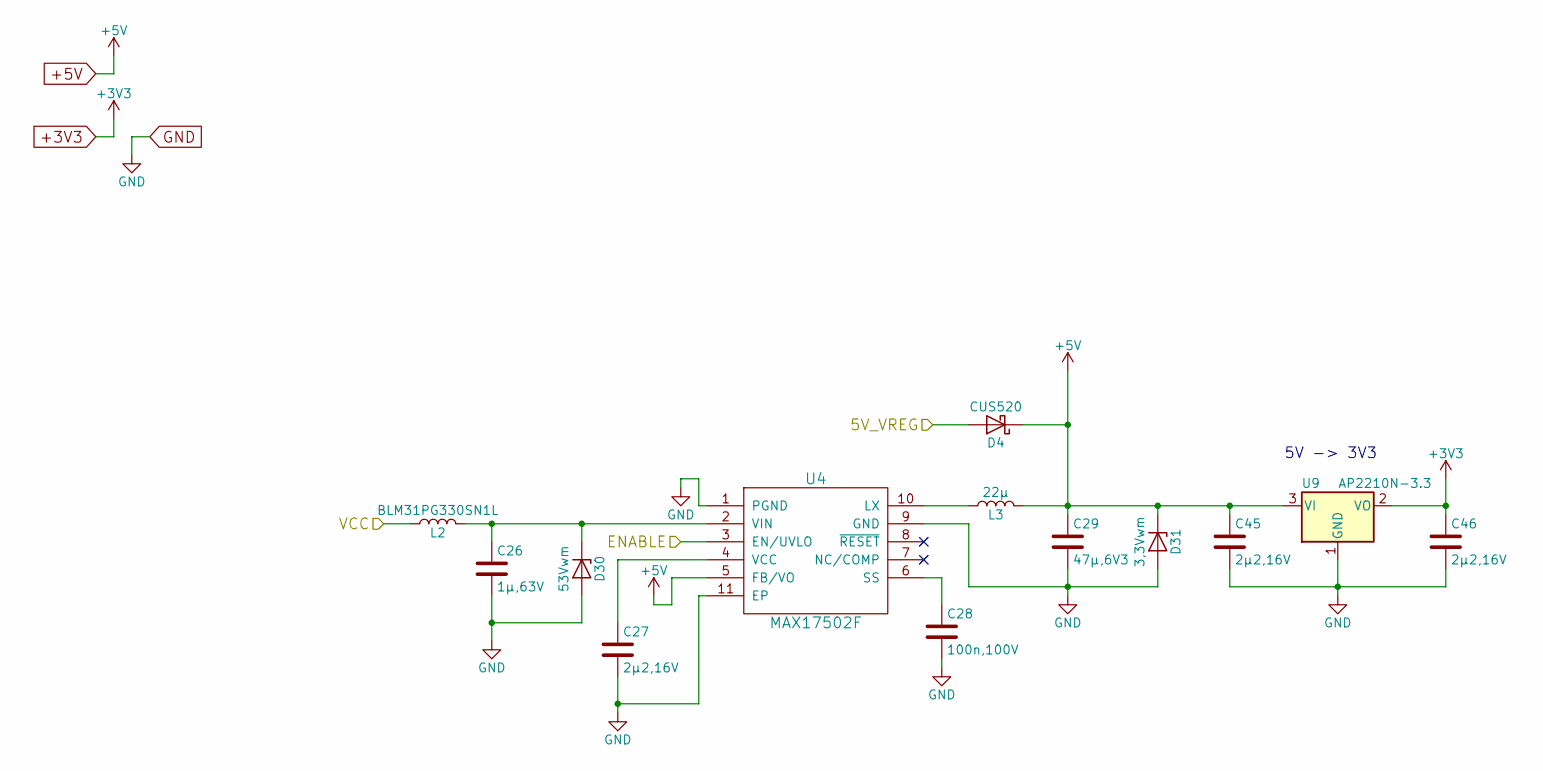
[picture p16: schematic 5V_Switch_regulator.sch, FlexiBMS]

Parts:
C26: 1µ,63V; C_1210
C27, C45, C46: 2µ2,16V; C_0603
C28: 100n,100V; C_0603
C29: 47µ,6V3; C_1206
D4: CUS520; D_SOD-323
D30: 53Vwm; D_SMA
D31: 3,3Vwm; D_SOD-123F
L2: BLM31PG330SN1L; L_1206
L3: 22µ; L_1210
U4: MAX17502F; DFN-10-1EP_2x3mm_Pitch0.5mm
U9: AP2210N-3.3; SOT-23

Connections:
+3V3: C46.1, U9.2 (VO); also elsewhere on the board
+5V: C29.1, C45.1, D4.1 (K), D31.1 (K), L3.2, U4.5 (FB/VO), U9.3 (VI)
/ChargeFET/TO_BATTERY: L2.1; also elsewhere on the board
/MAX17502/5V_VREG: D4.2 (A); also elsewhere on the board
/Microcontroller/5V_ENABLE: U4.3 (EN/UVLO); also elsewhere on the board
GND: C26.2, C27.2, C28.2, C29.2, C45.2, C46.2, D30.2 (A), D31.2 (A), U4.1 (PGND), U4.9 (GND), U4.11 (EP), U9.1 (GND); also elsewhere on the board
unnamed: C26.1, D30.1 (K), L2.2, U4.2 (VIN)
unnamed: C27.1, U4.4 (VCC)
unnamed: C28.1, U4.6 (SS)
unnamed: L3.1, U4.10 (LX)

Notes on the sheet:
5V -> 3V3

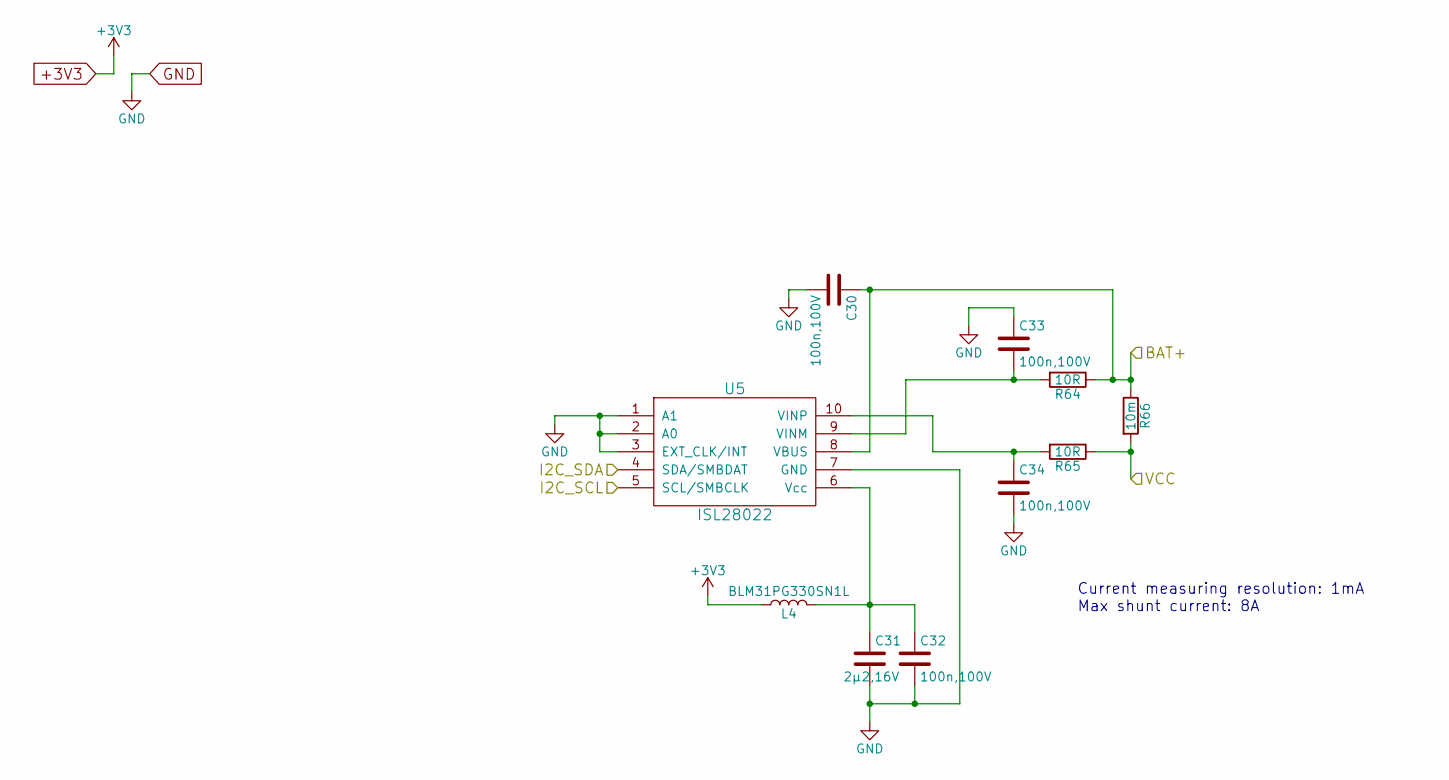
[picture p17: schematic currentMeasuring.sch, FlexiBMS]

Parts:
C30, C32, C33, C34: 100n,100V; C_0603
C31: 2µ2,16V; C_0603
L4: BLM31PG330SN1L; L_1206
R64, R65: 10R; R_0603
R66: 10m; R_1206
U5: ISL28022; MSOP-10_3x3mm_Pitch0.5mm

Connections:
+3V3: L4.1; also elsewhere on the board
/BAT+: C30.1, R64.1, R66.1, U5.8 (VBUS); also elsewhere on the board
/ChargeFET/TO_BATTERY: R65.1, R66.2; also elsewhere on the board
/I2C_SCL: U5.5 (SCL/SMBCLK); also elsewhere on the board
/I2C_SDA: U5.4 (SDA/SMBDAT); also elsewhere on the board
GND: C30.2, C31.2, C32.2, C33.1, C34.2, U5.1 (A1), U5.2 (A0), U5.3 (EXT_CLK/INT), U5.7 (GND); also elsewhere on the board
unnamed: C31.1, C32.1, L4.2, U5.6 (Vcc)
unnamed: C33.2, R64.2, U5.9 (VINM)
unnamed: C34.1, R65.2, U5.10 (VINP)

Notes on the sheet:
Current measuring resolution: 1mA Max shunt current: 8A

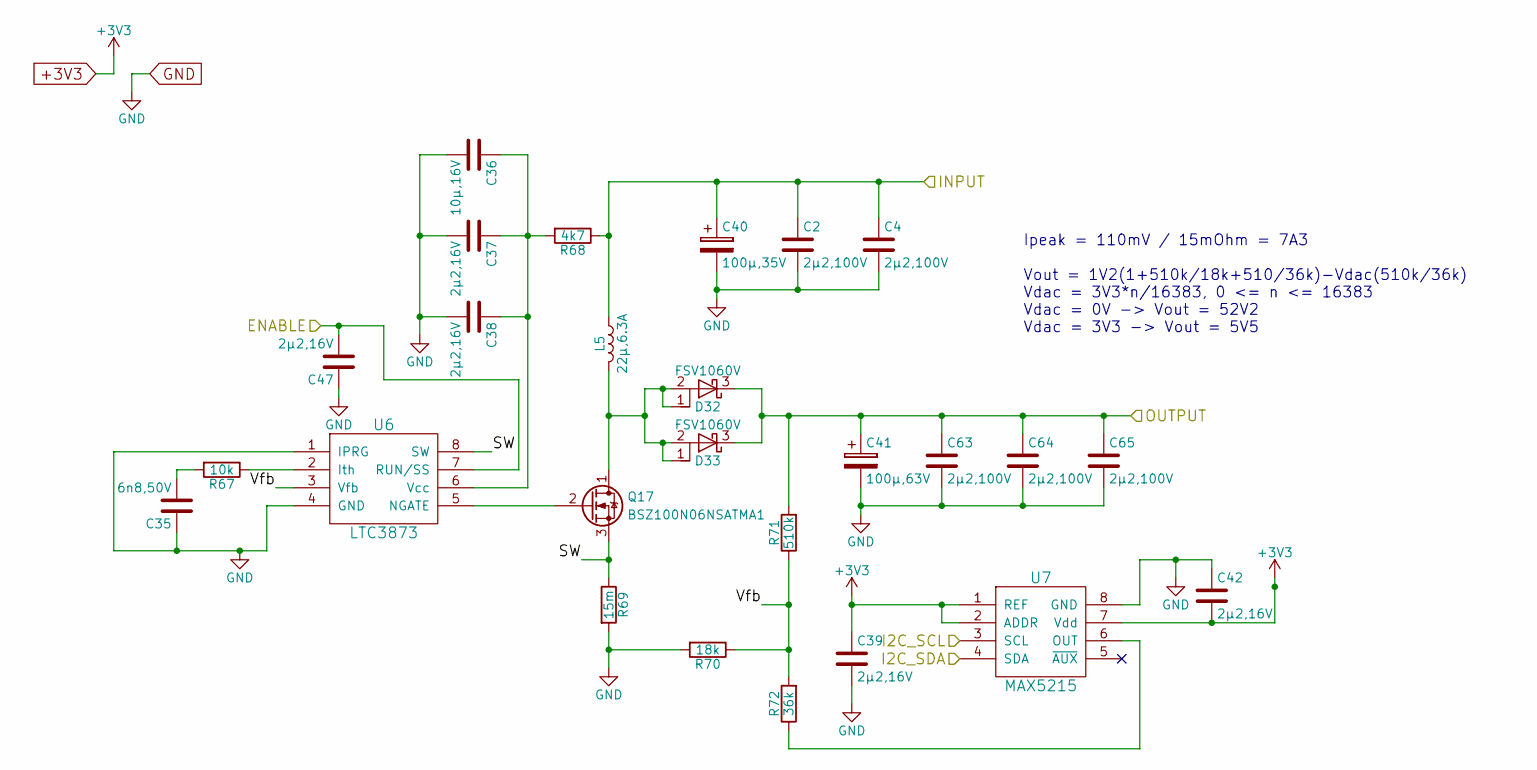
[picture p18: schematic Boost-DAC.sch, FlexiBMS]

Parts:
C2, C4, C63, C64, C65: 2µ2,100V; C_1210
C35: 6n8,50V; C_0603
C36: 10µ,16V; C_1206
C37, C38, C39, C42, C47: 2µ2,16V; C_0603
C40: 100µ,35V; CP_Elec_6.3x7.7
C41: 100µ,63V; CP_Elec_10x10
D32, D33: FSV1060V; TO-277A
L5: 22µ,6.3A; HC9
Q17: BSZ100N06NSATMA1; PG-TDSON-8
R67: 10k; R_0603
R68: 4k7; R_0603
R69: 15m; R_1206
R70: 18k; R_0603
R71: 510k; R_0603
R72: 36k; R_0603
U6: LTC3873; TSOT-23-8
U7: MAX5215; MSOP-8_3x3mm_Pitch0.65mm

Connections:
+3V3: C39.1, C42.2, U7.1 (REF), U7.2 (ADDR), U7.7 (Vdd); also elsewhere on the board
/BOOST_CHARGER: C2.1, C4.1, C40.1, L5.1, R68.1; also elsewhere on the board
/BOOST_ENABLE: C47.2, U6.7 (RUN/SS); also elsewhere on the board
/BULK_CHARGER: C41.1, C63.1, C64.1, C65.1, D32.3 (K), D33.3 (K), R71.2; also elsewhere on the board
/Boost-DAC/SW: Q17.3 (S), R69.1, U6.8 (SW)
/Boost-DAC/Vfb: R70.1, R71.1, R72.2, U6.3 (Vfb)
/I2C_SCL: U7.3 (SCL); also elsewhere on the board
/I2C_SDA: U7.4 (SDA); also elsewhere on the board
GND: C2.2, C4.2, C35.1, C36.2, C37.2, C38.2, C39.2, C40.2, C41.2, C42.1, C47.1, C63.2, C64.2, C65.2, R69.2, R70.2, U6.1 (IPRG), U6.4 (GND), U7.8 (GND); also elsewhere on the board
unnamed: C35.2, R67.2
unnamed: C36.1, C37.1, C38.1, R68.2, U6.6 (Vcc)
unnamed: D32.1 (A), D32.2 (A), D33.1 (A), D33.2 (A), L5.2, Q17.1 (D)
unnamed: Q17.2 (G), U6.5 (NGATE)
unnamed: R67.1, U6.2 (Ith)
unnamed: R72.1, U7.6 (OUT)

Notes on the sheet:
Ipeak = 110mV / 15mOhm = 7A3 Vout = 1V2(1+510k/18k+510/36k)-Vdac(510k/36k) Vdac = 3V3*n/16383, 0 <= n <= 16383 Vdac = 0V -> Vout = 52V2 Vdac = 3V3 -> Vout = 5V5

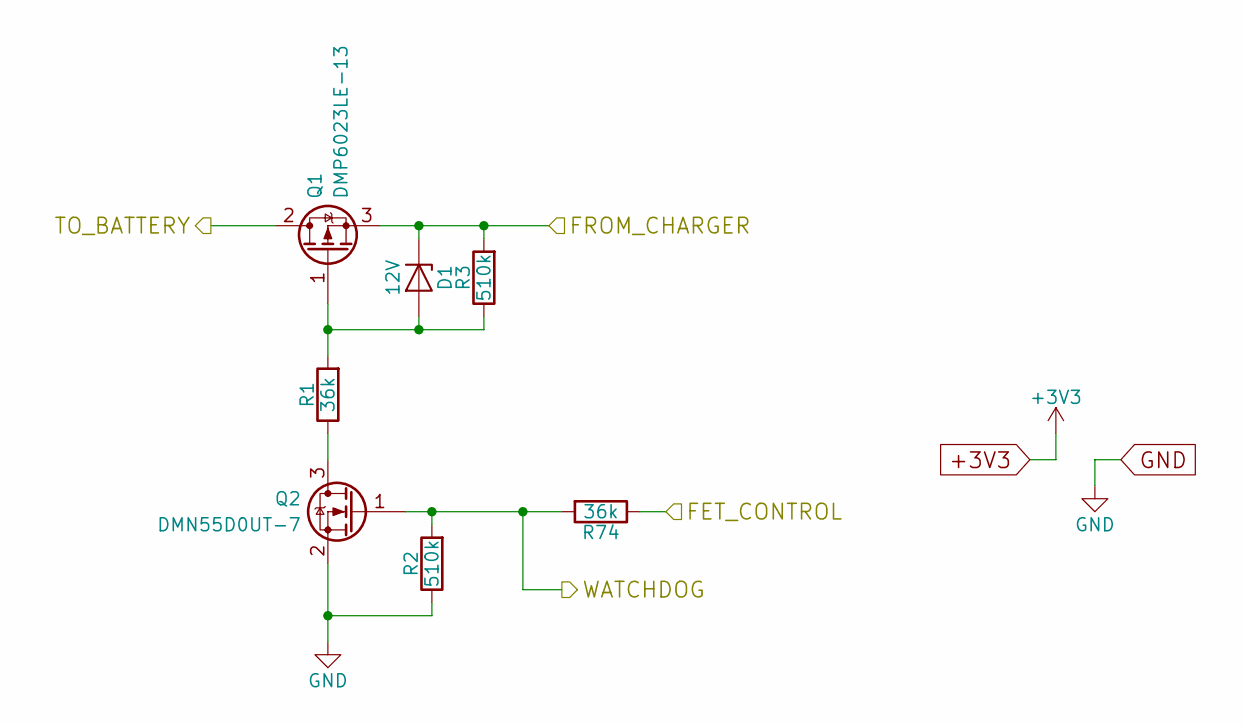
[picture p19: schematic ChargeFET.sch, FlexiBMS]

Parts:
D1: 12V; D_SOD-323
Q1: DMP6023LE-13; SOT-223-3_TabPin2
Q2: DMN55D0UT-7; SOT-523
R1, R74: 36k; R_0603
R2, R3: 510k; R_0603

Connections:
/BULK_CHARGER: D1.1 (K), Q1.3 (S), R3.2; also elsewhere on the board
/CHARGE_FET: R74.1; also elsewhere on the board
/ChargeFET/TO_BATTERY: Q1.2 (D); also elsewhere on the board
/WATCHDOG: Q2.1 (G), R2.2, R74.2; also elsewhere on the board
GND: Q2.2 (S), R2.1; also elsewhere on the board
unnamed: D1.2 (A), Q1.1 (G), R1.2, R3.1
unnamed: Q2.3 (D), R1.1

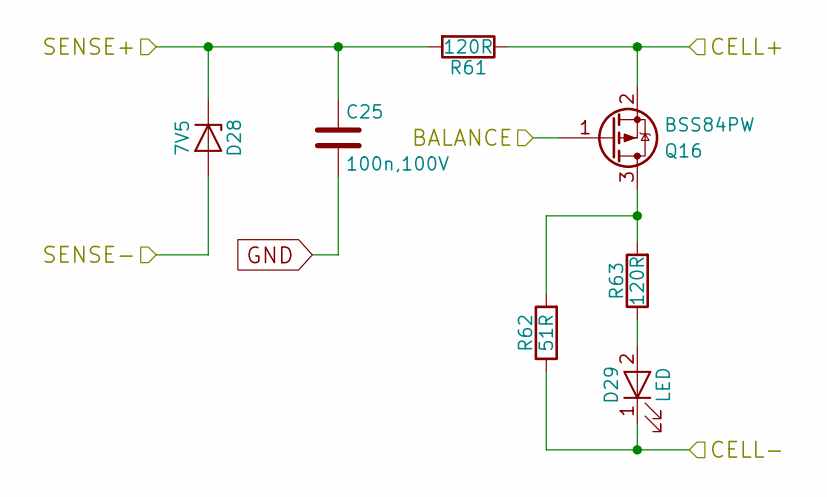
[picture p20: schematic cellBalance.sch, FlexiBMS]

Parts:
C14: 100n,100V; C_0603
D6: 7V5; D_SOD-323
D7: LED; LED_0603
Q5: BSS84PW; SOT-323_SC-70
R28, R30: 120R; R_0402
R29: 51R; R_0805

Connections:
/LTC6803-3/cellBalance_11/CELL+: D7.1 (K), R29.1; also elsewhere on the board
/LTC6803-3/cellBalance_11/SENSE+: D6.2 (A); also elsewhere on the board
/LTC6803-3/cellBalance_12/BALANCE: Q5.1 (G); also elsewhere on the board
/LTC6803-3/cellBalance_12/CELL+: Q5.2 (S), R28.1; also elsewhere on the board
/LTC6803-3/cellBalance_12/SENSE+: C14.1, D6.1 (K), R28.2; also elsewhere on the board
GND: C14.2; also elsewhere on the board
unnamed: D7.2 (A), R30.1
unnamed: Q5.3 (D), R29.2, R30.2

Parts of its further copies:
C15, C16, C17, C18, C19, C20, C21, C22, C23, C24, C25: 100n,100V; C_0603
D8, D10, D12, D14, D16, D18, D20, D22, D24, D26, D28: 7V5; D_SOD-323
D9, D11, D13, D15, D17, D19, D21, D23, D25, D27, D29: LED; LED_0603
Q6, Q7, Q8, Q9, Q10, Q11, Q12, Q13, Q14, Q15, Q16: BSS84PW; SOT-323_SC-70
R31, R33, R34, R36, R37, R39, R40, R42, R43, R45, R46, R48, R49, R51, R52, R54, R55, R57, R58, R60, R61, R63: 120R; R_0402
R32, R35, R38, R41, R44, R47, R50, R53, R56, R59, R62: 51R; R_0805

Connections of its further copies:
/LTC6803-3/cellBalance_1/BALANCE: Q16.1 (G); also elsewhere on the board
/LTC6803-3/cellBalance_1/CELL+: D27.1 (K), Q16.2 (S), R59.1, R61.1; also elsewhere on the board
/LTC6803-3/cellBalance_1/CELL-: D29.1 (K), R62.1; also elsewhere on the board
/LTC6803-3/cellBalance_1/SENSE+: C25.1, D26.2 (A), D28.1 (K), R61.2; also elsewhere on the board
/LTC6803-3/cellBalance_1/SENSE-: D28.2 (A); also elsewhere on the board
/LTC6803-3/cellBalance_2/BALANCE: Q15.1 (G); also elsewhere on the board
/LTC6803-3/cellBalance_2/CELL+: D25.1 (K), Q15.2 (S), R56.1, R58.1; also elsewhere on the board
/LTC6803-3/cellBalance_2/SENSE+: C24.1, D24.2 (A), D26.1 (K), R58.2; also elsewhere on the board
/LTC6803-3/cellBalance_3/BALANCE: Q14.1 (G); also elsewhere on the board
/LTC6803-3/cellBalance_3/CELL+: D23.1 (K), Q14.2 (S), R53.1, R55.1; also elsewhere on the board
/LTC6803-3/cellBalance_3/SENSE+: C23.1, D22.2 (A), D24.1 (K), R55.2; also elsewhere on the board
/LTC6803-3/cellBalance_4/BALANCE: Q13.1 (G); also elsewhere on the board
/LTC6803-3/cellBalance_4/CELL+: D21.1 (K), Q13.2 (S), R50.1, R52.1; also elsewhere on the board
/LTC6803-3/cellBalance_4/SENSE+: C22.1, D20.2 (A), D22.1 (K), R52.2; also elsewhere on the board
/LTC6803-3/cellBalance_5/BALANCE: Q12.1 (G); also elsewhere on the board
/LTC6803-3/cellBalance_5/CELL+: D19.1 (K), Q12.2 (S), R47.1, R49.1; also elsewhere on the board
/LTC6803-3/cellBalance_5/SENSE+: C21.1, D18.2 (A), D20.1 (K), R49.2; also elsewhere on the board
/LTC6803-3/cellBalance_6/BALANCE: Q11.1 (G); also elsewhere on the board
/LTC6803-3/cellBalance_6/CELL+: D17.1 (K), Q11.2 (S), R44.1, R46.1; also elsewhere on the board
/LTC6803-3/cellBalance_6/SENSE+: C20.1, D16.2 (A), D18.1 (K), R46.2; also elsewhere on the board
/LTC6803-3/cellBalance_7/BALANCE: Q10.1 (G); also elsewhere on the board
/LTC6803-3/cellBalance_7/CELL+: D15.1 (K), Q10.2 (S), R41.1, R43.1; also elsewhere on the board
/LTC6803-3/cellBalance_7/SENSE+: C19.1, D14.2 (A), D16.1 (K), R43.2; also elsewhere on the board
/LTC6803-3/cellBalance_8/BALANCE: Q9.1 (G); also elsewhere on the board
/LTC6803-3/cellBalance_8/CELL+: D13.1 (K), Q9.2 (S), R38.1, R40.1; also elsewhere on the board
/LTC6803-3/cellBalance_8/SENSE+: C18.1, D12.2 (A), D14.1 (K), R40.2; also elsewhere on the board
/LTC6803-3/cellBalance_9/BALANCE: Q8.1 (G); also elsewhere on the board
/LTC6803-3/cellBalance_9/CELL+: D11.1 (K), Q8.2 (S), R35.1, R37.1; also elsewhere on the board
/LTC6803-3/cellBalance_9/SENSE+: C17.1, D10.2 (A), D12.1 (K), R37.2; also elsewhere on the board
/LTC6803-3/cellBalance_10/BALANCE: Q7.1 (G); also elsewhere on the board
/LTC6803-3/cellBalance_10/CELL+: D9.1 (K), Q7.2 (S), R32.1, R34.1; also elsewhere on the board
/LTC6803-3/cellBalance_10/SENSE+: C16.1, D8.2 (A), D10.1 (K), R34.2; also elsewhere on the board
/LTC6803-3/cellBalance_11/BALANCE: Q6.1 (G); also elsewhere on the board
/LTC6803-3/cellBalance_11/CELL+: Q6.2 (S), R31.1; also elsewhere on the board
/LTC6803-3/cellBalance_11/SENSE+: C15.1, D8.1 (K), R31.2; also elsewhere on the board
GND: C15.2, C16.2, C17.2, C18.2, C19.2, C20.2, C21.2, C22.2, C23.2, C24.2, C25.2; also elsewhere on the board
unnamed: D9.2 (A), R33.1
unnamed: D11.2 (A), R36.1
unnamed: D13.2 (A), R39.1
unnamed: D15.2 (A), R42.1
unnamed: D17.2 (A), R45.1
unnamed: D19.2 (A), R48.1
unnamed: D21.2 (A), R51.1
unnamed: D23.2 (A), R54.1
unnamed: D25.2 (A), R57.1
unnamed: D27.2 (A), R60.1
unnamed: D29.2 (A), R63.1
unnamed: Q6.3 (D), R32.2, R33.2
unnamed: Q7.3 (D), R35.2, R36.2
unnamed: Q8.3 (D), R38.2, R39.2
unnamed: Q9.3 (D), R41.2, R42.2
unnamed: Q10.3 (D), R44.2, R45.2
unnamed: Q11.3 (D), R47.2, R48.2
unnamed: Q12.3 (D), R50.2, R51.2
unnamed: Q13.3 (D), R53.2, R54.2
unnamed: Q14.3 (D), R56.2, R57.2
unnamed: Q15.3 (D), R59.2, R60.2
unnamed: Q16.3 (D), R62.2, R63.2

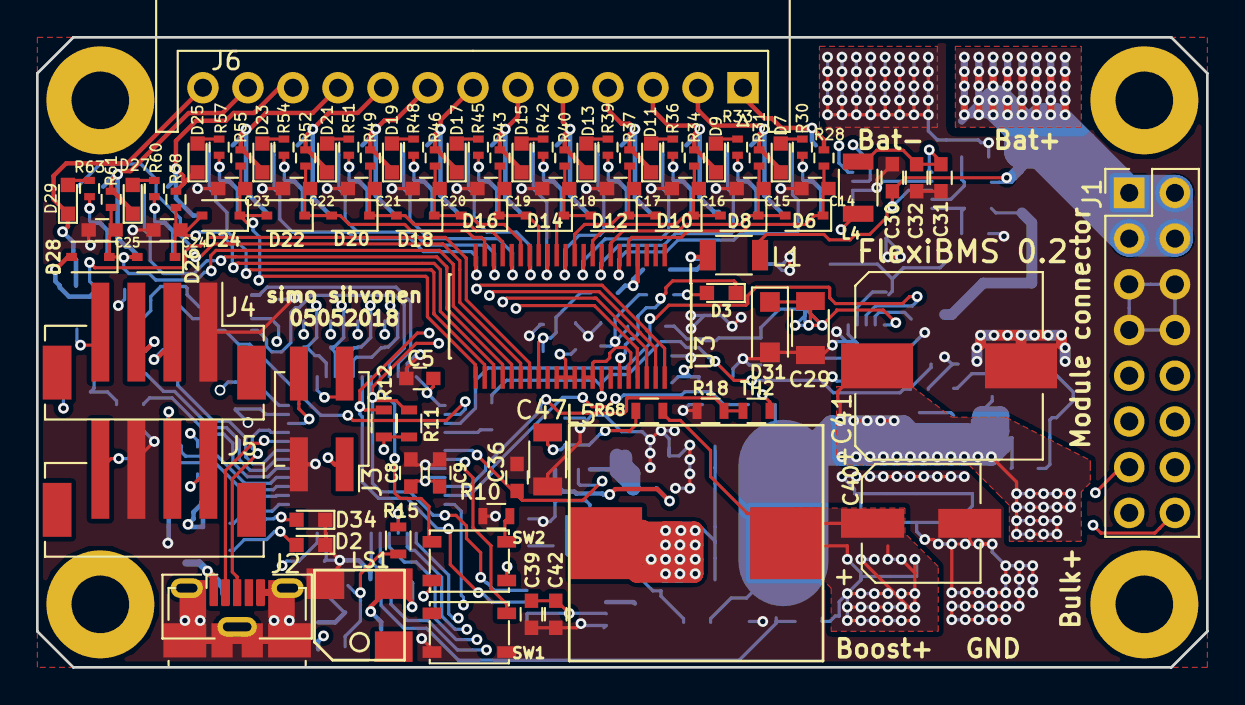
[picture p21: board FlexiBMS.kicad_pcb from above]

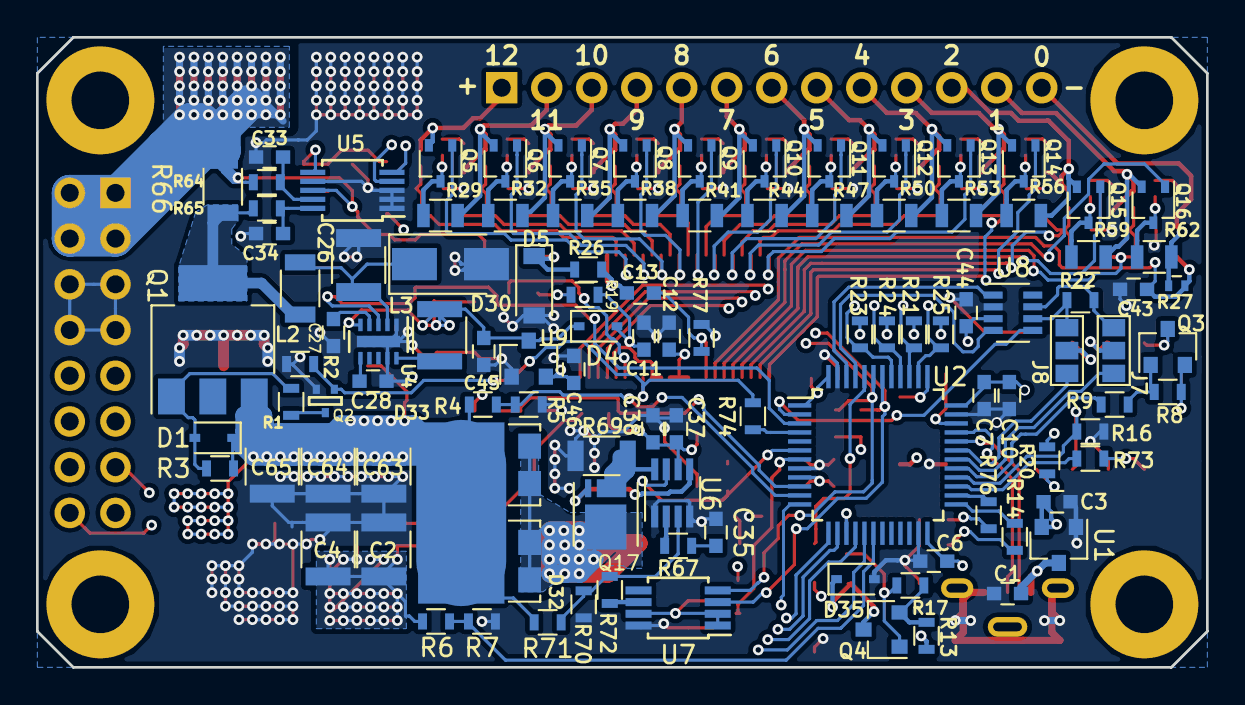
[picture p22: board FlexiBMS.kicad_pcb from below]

Board: 4 copper layers, 65.0 x 35.0 mm, 204 parts (107 on the bottom side), 142 nets.

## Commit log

2018-02-23 First prototype KiCad project files added -Changed the LTC6803-3 battery stack monitors schematic a little bit to conform better to it's datasheets reference design
    [3V3_Switch_regulator.sch, BMS_stack_monitor.sch, Boost-DAC-Watchdog.sch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]
2018-02-23 Removed some old and deprecated files not used in the current design.
    [Boost-DAC-Watchdog.sch, cell_balance.sch]
2018-02-26 0.1 Version finalized Silkscreen has been optimized, gerber files have been generated and boards have been ordered
    [FlexiBMS_01-B.Cu.gbl, FlexiBMS_01-B.Mask.gbs, FlexiBMS_01-B.Paste.gbp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]
2018-05-11 HW 0.2 finalized schematic and pcb files, BOM needs to be checked
    Lots of major and little problems fixed found in the 0.1
    Major changes:
    -LTC6803-3 footprint changed to it's correct one
    -Boost converter layout and capacitor optimization
    -MCU switched from STM32F070CBT6 to ultra low power STM32L433CCT6 to improve sleep state power consumption
    -Button/LED + Comms connectors switched from THT JST-XH to SMD JST-PH
    -CAN-bus support added
    -Changed power regulator setup for "always on"
    Minor changes:
    -Changed cell balance resistor sizes from 0603 to 0402 in order to get a bit more breathing room during soldering
    -External oscillator removed from MCU, because new one has everything available inte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
    [5V_Switch_regulator.sch, BMS_stack_monitor.sch, Boost-DAC.sch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]
2018-05-11 Updated revision dates on schematic pages and replaced old .pdf of the schematics with up-to-date one
    [5V_Switch_regulator.sch, BMS_stack_monitor.sch, Boost-DAC.sch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]
2018-05-29 Update README.md
    Updated the projects description to be more in line with it's current status
2018-05-29 0.2 HW files finalized and repo cleaned up.
    -BOM is now up-to-date and available in .csv and .pdf formats
    [5V_Switch_regulator.sch, BMS_stack_monitor.sch, Boost-DAC.sch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]
2018-05-30 Updated schematic .pdf added
